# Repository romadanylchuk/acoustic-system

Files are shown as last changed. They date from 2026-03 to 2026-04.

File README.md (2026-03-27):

# Акустична розвідувальна система

Система акустичної розвідки для спостережного пункту (СП) у польових умовах.

## Структура проекту

```
acoustic-system/
├── docs/
│   ├── acoustic_system_context.md      # Контекст проекту (для Claude)
│   └── bom_acoustic_system_v2.xlsx     # Специфікація комплектуючих
├── hardware/
│   ├── station_battery_mount.scad      # Акумуляторний відсік + кріплення
│   ├── station_electronics_compartment.scad  # Електронний відсік
│   └── station_mic_lid.scad            # Мікрофонна кришка
├── firmware/
│   ├── station/                        # Прошивка ESP32-S3 (автономна станція)
│   └── gateway/                        # Прошивка TTGO LoRa32 (базова станція)
├── server/                             # Серверна частина (Rock Pi 4C+)
└── README.md
```

## Відновлення контексту в Claude Code

```bash
claude
```

Після запуску:
```
Прочитай docs/acoustic_system_context.md і продовжимо розробку
```

## Поточний статус

- [x] Архітектура системи
- [x] Специфікація комплектуючих
- [x] 3D моделі корпусу (SCAD)
- [ ] Етап 1: Прошивка ESP32-S3 — 4-канальний запис + GCC-PHAT TDOA
- [ ] Етап 2: Протокол LoRa + передача аудіо
- [ ] Етап 3: Тестування на вулиці
- [ ] Етап 4: Серверна обробка + інтерфейс

## Тестова конфігурація

```
2× Автономна станція  (ESP32-S3 + 4×INMP441 + LoRa + nRF24)
1× Базова станція     (Rock Pi 4C+ + TTGO LoRa32 комунікаційний модуль)
Розміщення: трикутник ~300м сторона
```

## Апаратне забезпечення

| Компонент | Модель | К-сть |
|---|---|---|
| МК станції | ESP32-S3-DevKitC-1 N16R8 | 3 |
| Мікрофони | INMP441 I2S | 20 |
| Акумулятори | Li-Ion 21700 (2S2P на станцію) | 8 |
| LoRa | Ra-02 SX1278 433МГц | 2 |
| 2.4ГГц | nRF24L01 PA+LNA | 3 |
| RTC | DS3231 | 2 |
| DC-DC | Mini360 | 2 |
| BMS станції | 2S Li-Ion 8.4В | 2 |
| Одноплатний ПК | Rock Pi 4C+ | 1 |
| Комунікаційний модуль | TTGO LoRa32 SX1278 | 1 |
| BMS база | 4S Li-Ion 16.8В | 1 |
| DC-DC база | XL4016 | 1 |

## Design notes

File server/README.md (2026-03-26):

# Серверна частина (Rock Pi 4C+)

TTGO LoRa32 підключається до Rock Pi по USB/UART як комунікаційний модуль.
USB мікрофон підключається напряму до Rock Pi (станція 0).

## TODO

- [ ] Прийом даних від TTGO по USB/UART
- [ ] Розшифрування AES-128-CCM LoRa пакетів (counter + MIC верифікація)
- [ ] Тріангуляція позиції джерела звуку (6 TDOA пар на станцію)
- [ ] Класифікація нейромережею
- [ ] Трекінг переміщення
- [ ] Інтерфейс оператора (карта)

## Алгоритми

### Тріангуляція

1. **Bearing Intersection** — перетин напрямних від станцій
2. **TDOA між станціями** — по різниці часу надходження події

### Класифікація

Нейромережева класифікація джерела:
- Людина (кроки, голос)
- Тварина
- Транспорт (колісний, гусеничний)
- Невідомо

## Залежності (Python)

```
numpy
scipy
torch або tflite
pyserial
folium або leaflet (карта)
```

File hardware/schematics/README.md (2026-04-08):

# hardware/schematics — Текстові нетлісти схем

Цей каталог містить текстові нетлісти у форматі, сумісному з KiCad 8, для майбутнього проектування друкованих плат акустичної розвідувальної системи.

## Файли

| Файл | Опис |
|---|---|
| `station_netlist.txt` | Нетліст автономної станції (ESP32-S3 N16R8): 4× INMP441 по двох шинах I2S, Ra-02 SX1278 LoRa (SPI), nRF24L01 PA+LNA (спільна SPI шина з LoRa), DS3231 RTC (I2C), рейки живлення від LiFePO4 |
| `gateway_netlist.txt` | Нетліст шлюзу (TTGO LoRa32): зовнішній nRF24L01 PA+LNA (SPI), вбудований SX1278 LoRa 433 MHz, вбудований OLED-дисплей SSD1306, UART до сервера Rock Pi 4C+ |

## Формат та інструменти

Файли написані в S-expression форматі `(net-list ...)` — текстовий опис з'єднань.

**Інструмент:** KiCad 8 — редактор схем і трасування ДП.

## Воркфлоу редагування схем

**Джерело правди — `.kicad_sch` файли (KiCad S-expression).**

1. Перший `.kicad_sch` генерується з нетлісту (одноразово).
2. Розкладка компонентів робиться вручну в KiCad Eeschema (одноразово).
3. Всі подальші правки вносяться **напряму в `.kicad_sch`** — Claude може редагувати цей формат як текст.
4. Перегляд — відкрити/перезавантажити файл в KiCad Eeschema.

**Чому не skidl:** skidl при перегенерації скидає ручне розкладання компонентів. Для схем зі стабільною топологією це зайвий overhead.

```
Описати помилку → Claude править .kicad_sch → перевідкрити в KiCad → layout збережено
```

## Параметри запису (прототип)

- Частота дискретизації: **32 000 Гц / 16-bit**, 4 канали
- Кільцевий буфер: 32000 × 4 кан. × 2 байт × 15 с = **3.84 МБ** (в межах 8 МБ PSRAM модуля N16R8)
- Смуга: 16 кГц — покриває акустичні сигнатури БПЛА

## Серійний зразок (цільова апаратна платформа)

Серійна версія передбачає перехід на підвищені характеристики:

| Параметр | Прототип | Серійний зразок |
|---|---|---|
| МК | ESP32-S3 N16R8 | **STM32H743** |
| Мікрофони | INMP441 | **ICS-43434** (±0.5° фазова узгодженість) |
| Частота дискретизації | 32 000 Гц / 16-bit | **44 100 Гц / 24-bit** |
| Смуга | 16 кГц | 20 кГц |
| Буфер | 3.84 МБ | ~7.9 МБ (потребує зовнішнього SDRAM або ≤10 с буфера) |

Нетлісти для серійної версії будуть додані окремо після уточнення схемотехніки STM32H743.

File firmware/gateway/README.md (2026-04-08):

# Прошивка комунікаційного модуля (TTGO LoRa32)

TTGO LoRa32 — радіоміст між автономними станціями та Rock Pi 4C+.
Мікрофон СП (USB) підключається напряму до Rock Pi.

## TODO

- [ ] Прийом LoRa метаданих від автономних станцій
- [ ] Передача даних на Rock Pi по USB/UART
- [ ] Прийом аудіофрагментів по nRF24L01
- [ ] Відображення статусу на OLED дисплеї

## Підключення

### nRF24L01 (SPI)

| nRF24 | TTGO ESP32 | Примітка |
|---|---|---|
| MOSI | GPIO 13 | HSPI |
| MISO | GPIO 12 | HSPI |
| SCK | GPIO 15 | HSPI |
| CSN | GPIO 2 | |
| CE | GPIO 17 | |
| IRQ | GPIO 16 | |

> nRF24 підключений на HSPI шину — не конфліктує з вбудованим LoRa SX1278 (VSPI: MOSI=27, MISO=19, SCK=5, NSS=18). Firmware ініціалізує дві окремі SPI шини.

### OLED дисплей (вбудований на TTGO)

| Функція | Відображення |
|---|---|
| Рядок 1 | Кількість активних станцій |
| Рядок 2 | Остання подія (клас + час) |
| Рядок 3 | Рівень сигналу LoRa |
| Рядок 4 | Статус синхронізації |

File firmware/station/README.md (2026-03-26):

# Прошивка автономної станції (ESP32-S3)

## Конфігурація I2S (прототип)

| Параметр | Значення | Примітка |
|---|---|---|
| Sample rate | **32 000 Гц** | Bandwidth 16 kHz — покриває сигнатури БПЛА |
| Bit depth | **16 bit** | Зменшує вдвічі розмір буфера відносно 32-bit |
| Канали | 4 (2× I2S bus) | M1–M4 на шинах 0 і 1 |
| Ring buffer | 32000 × 4 × 2 × 15 с = **3.84 МБ** | Вміщується в 8 МБ PSRAM |

> **Серійний зразок (STM32H743 + ICS-43434):** підвищити до 44 100 Гц / 24-bit.
> ICS-43434 покриває до 20 kHz (±0.5° фазова узгодженість), що дає повний спектр
> для класифікації БПЛА і покращує роздільну здатність GCC-PHAT TDOA приблизно вдвічі.
> Buffer при цьому: 44100 × 4 × 3 × 15 с ≈ 7.9 МБ — потребує зовнішнього SDRAM або
> скорочення буфера до 10 с.

## Етап 1 — TODO

- [ ] Синхронний запис 4 каналів I2S (4× INMP441)
- [ ] Кільцевий буфер 10-15 сек в PSRAM (~3.84 МБ при 32кГц × 16bit × 4ch × 15s)
- [ ] GCC-PHAT алгоритм для TDOA між мікрофонами (6 пар)
- [ ] Попередня класифікація події
- [ ] Watchdog timer (обов'язково для автономної польової роботи)
- [ ] Deep sleep / light sleep керування живленням (~56мВт у режимі очікування)
- [ ] Пробудження через аналоговий компаратор (звуковий тригер)
- [ ] Читання температури з DS3231 (корекція швидкості звуку)
- [ ] Стратегія розподілу PSRAM (ring buffer + робочі буфери GCC-PHAT)
- [ ] SPI mutex для спільної шини LoRa + nRF24 (пріоритет: LoRa > nRF24)

## Етап 2 — TODO

- [ ] LoRa передача метаданих (Ra-02 SX1278)
- [ ] AES-128-CCM шифрування + автентифікація LoRa пакетів (pre-shared key)
- [ ] Прийом запиту з базової станції
- [ ] Передача аудіофрагменту по nRF24L01
- [ ] Переривання nRF24 передачі для пріоритетного LoRa пакету (SPI arbitration)

## Підключення

### INMP441 мікрофони (I2S)

| INMP441 | ESP32-S3 | Примітка |
|---|---|---|
| VDD | 3.3В | |
| GND | GND | |
| SCK | GPIO 14 | I2S шина 0 |
| WS | GPIO 15 | I2S шина 0 |
| SD | GPIO 16 | M1 (L/R=GND) |
| SD | GPIO 17 | M2 (L/R=3.3В) |
| SCK | GPIO 18 | I2S шина 1 |
| WS | GPIO 19 | I2S шина 1 |
| SD | GPIO 20 | M3 (L/R=GND) |
| SD | GPIO 21 | M4 (L/R=3.3В) |

### Ra-02 LoRa (SPI)

| Ra-02 | ESP32-S3 |
|---|---|
| MOSI | GPIO 11 |
| MISO | GPIO 13 |
| SCK | GPIO 12 |
| NSS | GPIO 10 |
| DIO0 | GPIO 9 |
| RST | GPIO 8 |

### nRF24L01 (SPI — спільна шина з LoRa)

| nRF24 | ESP32-S3 |
|---|---|
| MOSI | GPIO 11 |
| MISO | GPIO 13 |
| SCK | GPIO 12 |
| CSN | GPIO 7 |
| CE | GPIO 6 |
| IRQ | GPIO 5 |

### DS3231 RTC (I2C)

| DS3231 | ESP32-S3 |
|---|---|
| SDA | GPIO 3 |
| SCL | GPIO 4 |
| VCC | 3.3В |
| GND | GND |

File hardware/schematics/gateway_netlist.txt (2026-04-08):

;; KiCad-compatible Text Netlist
;; Gateway Node — TTGO LoRa32 (ESP32 + onboard SX1278 LoRa)
;; Acoustic Reconnaissance System — Gateway / Command Post (CP) Node
;; Generated from: firmware/gateway/README.md + docs/acoustic_system_context.md

(net-list
  (version 1)
  (design
    (source "acoustic-system/hardware/schematics/gateway_netlist.txt")
    (date "2026-03-23")
    (tool "hand-written / KiCad 8 compatible")
    (comment_1 "Board: TTGO LoRa32 (LILYGO T3 v1.6 or similar)")
    (comment_2 "MCU: ESP32 dual-core 240MHz, 4MB Flash, 8MB PSRAM (variant dependent)")
    (comment_3 "Onboard LoRa: SX1278 433MHz — connected internally, not in this netlist")
    (comment_4 "Onboard OLED: SSD1306 0.96\" 128x64 — connected internally via I2C")
    (comment_5 "External nRF24L01 PA+LNA connected via standard SPI pins")
  )

  ;; =========================================================
  ;; COMPONENTS
  ;; =========================================================

  (components

    ;; --- MCU + onboard peripherals ---
    (comp (ref U1)
      (value "TTGO LoRa32 ESP32")
      (description "ESP32 module on TTGO LoRa32 board. Onboard: SX1278 LoRa 433MHz, SSD1306 OLED 0.96\", LiPo charger")
    )

    ;; --- Onboard LoRa (internal wiring, informational) ---
    (comp (ref U2)
      (value "SX1278 (onboard)")
      (description "Onboard LoRa 433MHz transceiver on TTGO LoRa32. Internally wired to ESP32 SPI bus. Receives metadata packets from autonomous stations via FHSS.")
    )

    ;; --- Onboard OLED (internal wiring, informational) ---
    (comp (ref DSP1)
      (value "SSD1306 OLED 0.96\" (onboard)")
      (description "Onboard 128x64 OLED display on TTGO LoRa32. Internally wired via I2C. Shows: active station count, last event class+time, LoRa RSSI, sync status.")
    )

    ;; --- External nRF24L01 ---
    (comp (ref U3)
      (value "nRF24L01 PA+LNA")
      (description "External 2.4GHz radio module for on-demand audio fragment retrieval from autonomous stations. PA+LNA variant for extended range.")
    )

    ;; --- Power ---
    (comp (ref REG1)
      (value "3.3V onboard LDO")
      (description "3.3V regulator on TTGO LoRa32 board")
    )
  )

  ;; =========================================================
  ;; NETS
  ;; =========================================================

  (nets

    ;; ---------------------------------------------------------
    ;; POWER RAILS
    ;; ---------------------------------------------------------

    (net (name "+3V3")
      (node (ref U1)   (pin VDD))
      (node (ref U2)   (pin VCC))      ;; onboard, internal connection
      (node (ref DSP1) (pin VCC))      ;; onboard, internal connection
      (node (ref U3)   (pin VCC))
      (node (ref REG1) (pin OUT))
    )

    (net (name "GND")
      (node (ref U1)   (pin GND))
      (node (ref U2)   (pin GND))      ;; onboard, internal connection
      (node (ref DSP1) (pin GND))      ;; onboard, internal connection
      (node (ref U3)   (pin GND))
      (node (ref REG1) (pin GND))
    )

    ;; ---------------------------------------------------------
    ;; SPI BUS — external nRF24L01 PA+LNA
    ;; Uses HSPI bus (GPIO13/12/15) — free from LoRa conflicts.
    ;; TTGO T3 v1.6 LoRa uses: MOSI=27, MISO=19, SCK=5, NSS=18, RST=23
    ;; nRF24 is placed on separate HSPI to avoid conflicts.
    ;; ---------------------------------------------------------

    (net (name "NRF_SPI_MOSI")
      (node (ref U1)  (pin GPIO13))
      (node (ref U3)  (pin MOSI))
    )

    (net (name "NRF_SPI_MISO")
      (node (ref U1)  (pin GPIO12))
      (node (ref U3)  (pin MISO))
    )

    (net (name "NRF_SPI_SCK")
      (node (ref U1)  (pin GPIO15))
      (node (ref U3)  (pin SCK))
    )

    ;; ---------------------------------------------------------
    ;; nRF24L01 PA+LNA — control signals
    ;; ---------------------------------------------------------

    (net (name "NRF_CSN")
      (node (ref U1)  (pin GPIO2))
      (node (ref U3)  (pin CSN))
    )

    (net (name "NRF_CE")
      (node (ref U1)  (pin GPIO17))
      (node (ref U3)  (pin CE))
      ;; CE: chip enable — activates RX/TX mode
    )

    (net (name "NRF_IRQ")
      (node (ref U1)  (pin GPIO16))
      (node (ref U3)  (pin IRQ))
      ;; IRQ: active-low interrupt from nRF24 to MCU
    )

    ;; ---------------------------------------------------------
    ;; ONBOARD LoRa SX1278 — internal connections (informational)
    ;; Exact internal pin mapping varies by TTGO LoRa32 revision.
    ;; Common wiring for TTGO T3 v1.6:
    ;;   MOSI=GPIO27, MISO=GPIO19, SCK=GPIO5, NSS=GPIO18,
    ;;   DIO0=GPIO26, RST=GPIO23
    ;; Check board schematic for exact revision.
    ;; ---------------------------------------------------------

    (net (name "LORA_SPI_MOSI_INTERNAL")
      (node (ref U1)  (pin GPIO27))    ;; TTGO T3 v1.6 typical
      (node (ref U2)  (pin MOSI))
    )

    (net (name "LORA_SPI_MISO_INTERNAL")
      (node (ref U1)  (pin GPIO19))    ;; shared MISO on some revisions
      (node (ref U2)  (pin MISO))
    )

    (net (name "LORA_SPI_SCK_INTERNAL")
      (node (ref U1)  (pin GPIO5))     ;; TTGO T3 v1.6 typical
      (node (ref U2)  (pin SCK))
    )

    (net (name "LORA_NSS_INTERNAL")
      (node (ref U1)  (pin GPIO18))    ;; TTGO T3 v1.6 typical
      (node (ref U2)  (pin NSS))
    )

    (net (name "LORA_DIO0_INTERNAL")
      (node (ref U1)  (pin GPIO26))    ;; TTGO T3 v1.6 typical
      (node (ref U2)  (pin DIO0))
    )

    (net (name "LORA_RST_INTERNAL")
      (node (ref U1)  (pin GPIO23))    ;; TTGO T3 v1.6 typical
      (node (ref U2)  (pin RST))
    )

    ;; ---------------------------------------------------------
    ;; ONBOARD OLED SSD1306 — internal I2C connections (informational)
    ;; Common on TTGO LoRa32: SDA=GPIO21, SCL=GPIO22
    ;; ---------------------------------------------------------

    (net (name "I2C_SDA_INTERNAL")
      (node (ref U1)   (pin GPIO21))
      (node (ref DSP1) (pin SDA))
    )

    (net (name "I2C_SCL_INTERNAL")
      (node (ref U1)   (pin GPIO22))
      (node (ref DSP1) (pin SCL))
    )

    ;; ---------------------------------------------------------
    ;; USB/UART TO HOST (Rock Pi 4C+ server)
    ;; TTGO onboard USB-to-UART via CP2102 or CH340
    ;; Gateway relays LoRa metadata to server over serial
    ;; ---------------------------------------------------------

    (net (name "UART_TX_TO_HOST")
      (node (ref U1)  (pin TXD0))
      ;; Connected through onboard USB-UART chip to Rock Pi USB port
    )

    (net (name "UART_RX_FROM_HOST")
      (node (ref U1)  (pin RXD0))
      ;; Control commands from Rock Pi to gateway
    )

  ) ;; end nets

) ;; end net-list

;; =========================================================
;; PIN ASSIGNMENT SUMMARY — TTGO LoRa32 ESP32
;; =========================================================
;;
;;  GPIO  | Net Name                  | Connected To
;; -------|---------------------------|----------------------------
;;   2    | NRF_CSN                   | nRF24L01 CSN
;;   5    | LORA_SPI_SCK_INTERNAL     | SX1278 SCK  (onboard)
;;  12    | NRF_SPI_MISO              | nRF24L01 MISO  (HSPI)
;;  13    | NRF_SPI_MOSI              | nRF24L01 MOSI  (HSPI)
;;  15    | NRF_SPI_SCK               | nRF24L01 SCK   (HSPI)
;;  16    | NRF_IRQ                   | nRF24L01 IRQ
;;  17    | NRF_CE                    | nRF24L01 CE
;;  18    | LORA_NSS_INTERNAL         | SX1278 NSS  (onboard)
;;  19    | LORA_SPI_MISO_INTERNAL    | SX1278 MISO (onboard)
;;  21    | I2C_SDA_INTERNAL          | SSD1306 SDA (onboard)
;;  22    | I2C_SCL_INTERNAL          | SSD1306 SCL (onboard)
;;  23    | LORA_RST_INTERNAL         | SX1278 RST  (onboard)
;;  26    | LORA_DIO0_INTERNAL        | SX1278 DIO0 (onboard)
;;  27    | LORA_SPI_MOSI_INTERNAL    | SX1278 MOSI (onboard)
;;
;; nRF24 placed on HSPI (GPIO12/13/15) — no conflicts with onboard LoRa SPI.
;; Firmware must initialise two SPI buses: VSPI for LoRa (internal), HSPI for nRF24.
;;
;; =========================================================
;; OLED STATUS DISPLAY (onboard SSD1306)
;; =========================================================
;;
;;  Line 1: Number of active autonomous stations
;;  Line 2: Last event — class + timestamp
;;  Line 3: LoRa RSSI / signal level
;;  Line 4: Time synchronisation status
;;
;; =========================================================
;; GATEWAY ROLE IN SYSTEM
;; =========================================================
;;
;;  - Receives LoRa 433MHz FHSS metadata packets from all stations
;;  - Forwards decoded metadata to Rock Pi 4C+ server via USB/UART
;;  - Receives audio-request commands from server
;;  - Transmits nRF24L01 audio-pull requests to target station
;;  - Receives compressed Opus audio (16kHz mono, 32kbps) via nRF24
;;  - Relays audio stream to server for classification and archiving
;;
;; =========================================================

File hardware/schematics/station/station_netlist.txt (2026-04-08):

;; KiCad-compatible Text Netlist
;; Autonomous Station — ESP32-S3 (N16R8: 8MB Flash + 8MB PSRAM)
;; Acoustic Reconnaissance System — Station Node
;; I2S recording: 32 000 Hz / 16-bit, 4 channels, ring buffer 3.84 MB in PSRAM
;; Generated from: firmware/station/README.md + docs/acoustic_system_context.md
;; Serial version target: STM32H743 + ICS-43434 @ 44 100 Hz / 24-bit

(net-list
  (version 1)
  (design
    (source "acoustic-system/hardware/schematics/station_netlist.txt")
    (date "2026-03-23")
    (tool "hand-written / KiCad 8 compatible")
    (comment_1 "Prototype MCU: ESP32-S3-DevKitC-1 N16R8")
    (comment_2 "Serial MCU target: STM32H743")
    (comment_3 "I2S sample rate: 32 000 Hz / 16-bit (prototype)")
    (comment_4 "Serial version: 44 100 Hz / 24-bit with ICS-43434 microphones")
  )

  ;; =========================================================
  ;; COMPONENTS
  ;; =========================================================

  (components

    ;; --- MCU ---
    (comp (ref U1)
      (value "ESP32-S3-DevKitC-1 N16R8")
      (description "Dual-core 240MHz, 8MB Flash, 8MB PSRAM")
    )

    ;; --- Microphones (I2S Bus 0) ---
    (comp (ref MIC1)
      (value "INMP441")
      (description "I2S MEMS microphone, M1, L/R pin = GND (left channel)")
    )
    (comp (ref MIC2)
      (value "INMP441")
      (description "I2S MEMS microphone, M2, L/R pin = VCC (right channel)")
    )

    ;; --- Microphones (I2S Bus 1) ---
    (comp (ref MIC3)
      (value "INMP441")
      (description "I2S MEMS microphone, M3, L/R pin = GND (left channel)")
    )
    (comp (ref MIC4)
      (value "INMP441")
      (description "I2S MEMS microphone, M4, L/R pin = VCC (right channel)")
    )

    ;; --- LoRa Radio ---
    (comp (ref U2)
      (value "Ra-02 SX1278")
      (description "LoRa module 433 MHz, FHSS, SPI interface")
    )

    ;; --- 2.4 GHz Radio ---
    (comp (ref U3)
      (value "nRF24L01 PA+LNA")
      (description "2.4 GHz radio, SPI shared with LoRa, on-demand audio transfer")
    )

    ;; --- RTC ---
    (comp (ref U4)
      (value "DS3231")
      (description "RTC with TCXO, I2C interface, temperature sensor for sound-speed correction")
    )

    ;; --- Power ---
    (comp (ref REG1)
      (value "Mini360 DC-DC buck")
      (description "DC-DC buck converter 7.4V->3.3V, ~90% efficiency")
    )
    (comp (ref BAT1)
      (value "Li-Ion 21700 x4 (2S2P)")
      (description "4x Li-Ion 21700 cells: 2S2P, 7.4V nominal / 8.4V charged / 6.0V cutoff, ~9Ah, ~67Wh. BMS 2S required.")
    )
  )

  ;; =========================================================
  ;; NETS
  ;; =========================================================

  (nets

    ;; ---------------------------------------------------------
    ;; POWER RAILS
    ;; ---------------------------------------------------------

    (net (name "+3V3")
      (node (ref U1)   (pin VDD))
      (node (ref MIC1) (pin VDD))
      (node (ref MIC2) (pin VDD))
      (node (ref MIC2) (pin LR))       ;; MIC2 L/R=VCC -> right channel
      (node (ref MIC3) (pin VDD))
      (node (ref MIC4) (pin VDD))
      (node (ref MIC4) (pin LR))       ;; MIC4 L/R=VCC -> right channel
      (node (ref U2)   (pin VCC))
      (node (ref U3)   (pin VCC))
      (node (ref U4)   (pin VCC))
      (node (ref REG1) (pin OUT))
    )

    (net (name "GND")
      (node (ref U1)   (pin GND))
      (node (ref MIC1) (pin GND))
      (node (ref MIC1) (pin LR))       ;; MIC1 L/R=GND -> left channel
      (node (ref MIC2) (pin GND))
      (node (ref MIC3) (pin GND))
      (node (ref MIC3) (pin LR))       ;; MIC3 L/R=GND -> left channel
      (node (ref MIC4) (pin GND))
      (node (ref U2)   (pin GND))
      (node (ref U3)   (pin GND))
      (node (ref U4)   (pin GND))
      (node (ref REG1) (pin GND))
      (node (ref BAT1) (pin NEG))
    )

    (net (name "VBAT")
      (node (ref BAT1) (pin POS))
      (node (ref REG1) (pin IN))
    )

    ;; ---------------------------------------------------------
    ;; I2S BUS 0 — MIC1 (M1) and MIC2 (M2)
    ;; ESP32-S3: SCK=GPIO14, WS=GPIO15
    ;; ---------------------------------------------------------

    (net (name "I2S0_SCK")
      (node (ref U1)   (pin GPIO14))
      (node (ref MIC1) (pin SCK))
      (node (ref MIC2) (pin SCK))
    )

    (net (name "I2S0_WS")
      (node (ref U1)   (pin GPIO15))
      (node (ref MIC1) (pin WS))
      (node (ref MIC2) (pin WS))
    )

    (net (name "I2S0_DATA_M1")
      (node (ref U1)   (pin GPIO16))
      (node (ref MIC1) (pin SD))
      ;; MIC1: L/R=GND => left channel, drives SD when WS=low
    )

    (net (name "I2S0_DATA_M2")
      (node (ref U1)   (pin GPIO17))
      (node (ref MIC2) (pin SD))
      ;; MIC2: L/R=VCC => right channel, drives SD when WS=high
    )

    ;; ---------------------------------------------------------
    ;; I2S BUS 1 — MIC3 (M3) and MIC4 (M4)
    ;; ESP32-S3: SCK=GPIO18, WS=GPIO19
    ;; ---------------------------------------------------------

    (net (name "I2S1_SCK")
      (node (ref U1)   (pin GPIO18))
      (node (ref MIC3) (pin SCK))
      (node (ref MIC4) (pin SCK))
    )

    (net (name "I2S1_WS")
      (node (ref U1)   (pin GPIO19))
      (node (ref MIC3) (pin WS))
      (node (ref MIC4) (pin WS))
    )

    (net (name "I2S1_DATA_M3")
      (node (ref U1)   (pin GPIO20))
      (node (ref MIC3) (pin SD))
      ;; MIC3: L/R=GND => left channel
    )

    (net (name "I2S1_DATA_M4")
      (node (ref U1)   (pin GPIO21))
      (node (ref MIC4) (pin SD))
      ;; MIC4: L/R=VCC => right channel
    )

    ;; ---------------------------------------------------------
    ;; SPI BUS (shared) — Ra-02 LoRa + nRF24L01
    ;; ESP32-S3: MOSI=GPIO11, MISO=GPIO13, SCK=GPIO12
    ;; Chip selects are separate (LORA_NSS, NRF_CSN)
    ;; ---------------------------------------------------------

    (net (name "SPI_MOSI")
      (node (ref U1)  (pin GPIO11))
      (node (ref U2)  (pin MOSI))
      (node (ref U3)  (pin MOSI))
    )

    (net (name "SPI_MISO")
      (node (ref U1)  (pin GPIO13))
      (node (ref U2)  (pin MISO))
      (node (ref U3)  (pin MISO))
    )

    (net (name "SPI_SCK")
      (node (ref U1)  (pin GPIO12))
      (node (ref U2)  (pin SCK))
      (node (ref U3)  (pin SCK))
    )

    ;; ---------------------------------------------------------
    ;; LoRa Ra-02 SX1278 — control signals
    ;; ---------------------------------------------------------

    (net (name "LORA_NSS")
      (node (ref U1)  (pin GPIO10))
      (node (ref U2)  (pin NSS))
    )

    (net (name "LORA_DIO0")
      (node (ref U1)  (pin GPIO9))
      (node (ref U2)  (pin DIO0))
      ;; DIO0: interrupt line — RxDone / TxDone / CadDone
    )

    (net (name "LORA_RST")
      (node (ref U1)  (pin GPIO8))
      (node (ref U2)  (pin RST))
    )

    ;; ---------------------------------------------------------
    ;; nRF24L01 PA+LNA — control signals
    ;; ---------------------------------------------------------

    (net (name "NRF_CSN")
      (node (ref U1)  (pin GPIO7))
      (node (ref U3)  (pin CSN))
    )

    (net (name "NRF_CE")
      (node (ref U1)  (pin GPIO6))
      (node (ref U3)  (pin CE))
      ;; CE: chip enable — activates RX/TX mode
    )

    (net (name "NRF_IRQ")
      (node (ref U1)  (pin GPIO5))
      (node (ref U3)  (pin IRQ))
      ;; IRQ: active-low interrupt from nRF24 to MCU
    )

    ;; ---------------------------------------------------------
    ;; I2C BUS — DS3231 RTC
    ;; ESP32-S3: SDA=GPIO3, SCL=GPIO4
    ;; ---------------------------------------------------------

    (net (name "I2C_SDA")
      (node (ref U1)  (pin GPIO3))
      (node (ref U4)  (pin SDA))
    )

    (net (name "I2C_SCL")
      (node (ref U1)  (pin GPIO4))
      (node (ref U4)  (pin SCL))
    )

  ) ;; end nets

) ;; end net-list

;; =========================================================
;; PIN ASSIGNMENT SUMMARY — ESP32-S3
;; =========================================================
;;
;;  GPIO  | Net Name         | Connected To
;; -------|------------------|-------------------------------
;;    3   | I2C_SDA          | DS3231 SDA
;;    4   | I2C_SCL          | DS3231 SCL
;;    5   | NRF_IRQ          | nRF24L01 IRQ
;;    6   | NRF_CE           | nRF24L01 CE
;;    7   | NRF_CSN          | nRF24L01 CSN
;;    8   | LORA_RST         | Ra-02 RST
;;    9   | LORA_DIO0        | Ra-02 DIO0
;;   10   | LORA_NSS         | Ra-02 NSS
;;   11   | SPI_MOSI         | Ra-02 MOSI + nRF24L01 MOSI
;;   12   | SPI_SCK          | Ra-02 SCK  + nRF24L01 SCK
;;   13   | SPI_MISO         | Ra-02 MISO + nRF24L01 MISO
;;   14   | I2S0_SCK         | MIC1 SCK, MIC2 SCK
;;   15   | I2S0_WS          | MIC1 WS,  MIC2 WS
;;   16   | I2S0_DATA_M1     | MIC1 SD   (L/R=GND, left)
;;   17   | I2S0_DATA_M2     | MIC2 SD   (L/R=VCC, right)
;;   18   | I2S1_SCK         | MIC3 SCK, MIC4 SCK
;;   19   | I2S1_WS          | MIC3 WS,  MIC4 WS
;;   20   | I2S1_DATA_M3     | MIC3 SD   (L/R=GND, left)
;;   21   | I2S1_DATA_M4     | MIC4 SD   (L/R=VCC, right)
;;
;; =========================================================
;; MICROPHONE TETRAHEDRAL ARRAY GEOMETRY
;; =========================================================
;;
;;  MIC1 (M1) — top apex of tetrahedron (vertical, pointing up)
;;  MIC2 (M2) — 35° tilt from vertical, azimuth 0°
;;  MIC3 (M3) — 35° tilt from vertical, azimuth 120°
;;  MIC4 (M4) — 35° tilt from vertical, azimuth 240°
;;
;;  35.26° tilt = true regular tetrahedron geometry
;;  Enables 3D direction-of-arrival: azimuth + elevation
;;  GCC-PHAT TDOA computed between all mic pairs.
;;  Temperature from DS3231 used for sound-speed correction
;;  (approx. 0.6 m/s per degree Celsius).
;;
;; =========================================================
;; RECORDING PARAMETERS
;; =========================================================
;;
;;  Prototype:    32 000 Hz / 16-bit / 4 channels
;;                Ring buffer: 32000 x 4ch x 2B x 15s = 3.84 MB
;;                Fits in 8 MB PSRAM (N16R8 module)
;;                Bandwidth: 16 kHz (covers UAV acoustic signatures)
;;
;;  Serial version target (future):
;;                44 100 Hz / 24-bit / 4 channels
;;                MCU: STM32H743, Mics: ICS-43434
;;                Buffer: ~7.9 MB — requires external SDRAM or <=10s buffer
;;
;; =========================================================

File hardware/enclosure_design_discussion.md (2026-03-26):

# Обговорення концепції нового корпусу станції

> Статус: обговорення, до проектування не переходили.
> Дата: 2026-03-25

## Зміна підходу відносно попередньої версії

Попередня версія: верхня + нижня кришка, електроніка знизу.

**Нова концепція — навпаки:**
- Верхня частина = основний корпус (відкрита знизу "чашка"), містить всю електроніку.
- Нижня частина = плоска кришка, яка закриває корпус знизу.

---

## Верхній корпус (основна деталь)

- Відкритий знизу.
- **Верхня панель:** 4 отвори під мікрофони INMP441 у тетраедральній геометрії (1 центральний або зміщений + 3 по колу на 120°). Мікрофонні плати монтуються зсередини, притискаються до верхньої панелі.
- **Бічні стінки:** 2 роз'єми SMA — для LoRa 433MHz антени та nRF24 2.4GHz антени.
- **По внутрішньому периметру нижнього краю:** горизонтальний порожок (полиця/уступ) — кришка спирається по всьому колу (для ущільнювача і щільного прилягання).
- **У кутах:** циліндричні бонки з отворами під шурупи з потаєм.

## Нижня кришка

- Плоска пластина, "втоплена" в порожок — не виступає за межі стінок корпусу.
- По кутах: наскрізні отвори з потаєм під головку шурупа.
- Знизу: кріплення під батарейний відсік (обговорення окремо).

---

## Внутрішнє компонування (знизу вгору при збірці)

1. **Спочатку** — мікрофонні плати. Вставляються і фіксуються до верхньої панелі зсередини.
2. **Потім** — макетна/монтажна плата з основною електронікою: ESP32-S3, Ra-02 LoRa, nRF24L01, DS3231, перехідні роз'єми, з'єднувачі до мікрофонів і антенних роз'ємів.

---

## Основні параметри (вирішено)

| Параметр | Значення |
|---|---|
| Макетна плата | 70×90 мм, горизонтально |
| Кріплення плати | Пластикові бонки під саморізи (висота регульована) |
| Мікрофони | 4× INMP441, тетраедр, на верхній панелі |
| Антени | 2× SMA збоку |
| Батареї | 4× Li-ion 21700 (⌀21×70мм), схема 2S2P, знизу окремим відсіком |

## Відкриті питання

1. Відстань між мікрофонними платами і макетною платою (висота бонок).
2. Кріплення батарейного відсіку до нижньої кришки (знімний чи глухий, де роз'єм зарядки).
3. IP-клас захисту → геометрія ущільнювача в порожку.

---

## Інструментарій

- **3D моделювання:** build123d (Python)
- **Перегляд:** ocp-vscode (`show(obj)`)
- Старі .scad файли — legacy, не використовувати.

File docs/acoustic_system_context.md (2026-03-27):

# Акустична розвідувальна система — Контекст проекту

> Документ для відновлення контексту розробки. Вставити на початку нової сесії з Claude.

---

## 1. Концепція системи

**Призначення:** Акустична розвідка для спостережного пункту (СП) у польових умовах. Визначення джерела, напрямку і характеру звуку в реальному часі.

**Принцип роботи:** Мережа автономних акустичних станцій збирає звук, обчислює TDOA (різниця часу надходження між мікрофонами), передає метадані на СП. Сервер тріангулює точну позицію джерела звуку і класифікує його (людина / тварина / транспорт).

**Радіус покриття:** До 3-5 км від сервера. Відстань між станціями — до 500м.

**Час реакції:** Одиниці секунд — прийнятно.

---

## 2. Архітектура

**Топологія мережі:** Mesh — кожна станція є і сенсором, і ретранслятором. Немає єдиної точки відмови. При виході станції з ладу мережа перебудовується автоматично.

**Два радіоканали:**
- LoRa 433МГц (FHSS) — метадані подій, керуючі команди, синхронізація. Завжди активний, мінімальна радіопомітність. Шифрування AES-128-CCM (pre-shared key).
- 2.4ГГц nRF24L01 PA+LNA — аудіофрагменти. Вмикається тільки за запитом СП на 15-20 сек.

**Безпека радіоканалу:**
- AES-128-CCM шифрування + автентифікація всіх LoRa пакетів (вбудоване в ESP32)
- 4-байт лічильник пакетів (захист від replay-атак)
- 4-байт MIC (Message Integrity Code) — захист від підробки
- Pre-shared 128-біт ключ, унікальний для кожного розгортання

**Спільна SPI шина (LoRa + nRF24):**
- LoRa і nRF24 використовують одну SPI шину з окремими CS лініями
- Firmware mutex: одночасний доступ заборонений
- Пріоритет: LoRa пакет перериває nRF24 аудіо передачу (pause/resume)

**Передача аудіо за запитом:** Станція має кільцевий буфер 10-15 сек у PSRAM (pre+post trigger, ~3.84 МБ при 32кГц × 16bit × 4ch × 15s) ( Bandwidth 16 kHz покриває акустичні сигнатури БПЛА (основні гармоніки до 12 кГц)). Сервер отримує метадані від всіх станцій → обирає 1-2 з найкращим SNR → надсилає запит → станція вмикає 2.4ГГц передавач і відправляє стиснений фрагмент (Opus, 16кГц mono, ~32кбіт/с).

**Мікрофон на СП:** СП має власний USB мікрофон як нульова станція. Якщо подія близько (~200-500м) — аудіо є без запиту до станцій.

**3D локалізація:** Тетраедральний масив 4 мікрофонів на кожній станції дає 3D напрямок (азимут + елевація). Розташування: 1 мікрофон вгору, 3 по колу під 120° з нахилом 35° від вертикалі (≈35.26° — правильний тетраедр). TDOA обчислюється для всіх 6 пар мікрофонів (C(4,2)). Сервер тріангулює позицію методами Bearing Intersection + TDOA між станціями.

---

## 3. Апаратна частина станції

**Процесор:**
- Прототип: ESP32-S3-DevKitC-1 N16R8 (16МБ Flash + 8МБ PSRAM, dual-core 240МГц)
- Фінальна версія: STM32H743 (краща енергетика, 4× незалежних I2S шини)

**Мікрофони:** 4× INMP441 I2S модуль (прототип) або ICS-43434 (фінал, фазова узгодженість ±0.5°). Розташування тетраедральне. Вітрозахисні поролонові насадки обов'язкові.

> **Серійний зразок — збільшення смуги:** перехід на 44 100 Гц / 24-bit з мікрофонами ICS-43434 (частотна характеристика до 20 кГц). Дає повний спектр для класифікації БПЛА та подвоює роздільну здатність GCC-PHAT TDOA. Потребує зовнішнього SDRAM або скорочення ring buffer до 10 с (буфер ~7.9 МБ).

**Синхронізація часу:**
- TCXO ±0.5ppm на кожній станції (дрейф ~1.5мкс/год)
- Калібрування: акустичний маяк при розгортанні + взаємна корекція між станціями по LoRa
- БЕЗ GPS — вразливий до РЕБ

**Живлення:**
- Li-ion 21700, схема 2S2P (4 елементи): 7.4В номінал / 8.4В заряд / 6.0В відсічка
- Ємність: ~9А·год (2P × ~4.5А·год), енергія ~67Вт·год
- DC-DC buck конвертер 7.4В→3.3В обов'язковий (ESP32-S3 та вся периферія 3.3В)
- BMS: 2S балансуючий із захистом (перезаряд, переразряд, КЗ)
- Середнє споживання ~75мВт → автономність ~30 діб (при 0°C і вище, ККД buck ~90%)
- При -20°C: ~15-18 діб (Li-ion втрачає ~30-40% ємності на морозі — слабше ніж LiFePO4). Підігрів при температурі нижче -10°C

**Режими роботи:**
- Очікування (95% часу): мікроконтролер у light sleep, аналоговий компаратор слухає (~56мВт)
- Обробка події (4%): пробудження, 4-канальний запис, GCC-PHAT TDOA (6 пар), класифікація (~330мВт)
- Передача LoRa (1%): пакет ~50 байт (з AES-128-CCM) кожні кілька секунд (~400мВт × 0.5 сек)

**Firmware вимоги (ESP32-S3):**
- Watchdog timer — обов'язково для автономної роботи без обслуговування
- Deep sleep / light sleep — реалізація енергетичних режимів
- Аналоговий компаратор — пробудження по звуковому порогу
- Температура з DS3231 — корекція швидкості звуку (±0.6 м/с на °C)
- PSRAM: кільцевий буфер ~3.84 МБ + робочі буфери GCC-PHAT + стек
- SPI mutex (LoRa + nRF24): пріоритет LoRa, pause/resume для nRF24 аудіо

**Корпус:** IP65 пластик мінімум. Кабельні вводи PG7/PG9 для герметизації. Передбачити місце для сонячної панелі (не реалізовано, але конструктивно закладено).

---

## 4. Базова станція / СП

**Обладнання:**
- Rock Pi 4C+ (4ГБ) — основний обчислювальний модуль
- TTGO LoRa32 SX1278 — комунікаційний модуль (тільки LoRa прийом + nRF24 аудіо), USB/UART → Rock Pi
- ESP32-S3 N16R8 — станція 0: 4× INMP441, та сама прошивка що й польові станції, USB CDC → Rock Pi
- SSD 256ГБ для логів і аудіоархіву

**Програмна обробка:**
- Тріангуляція позиції (Bearing Intersection + TDOA між станціями)
- Класифікація звуку нейромережею (людина / тварина / транспорт / невідомо)
- Трекінг переміщення — побудова траєкторії об'єкта
- Фільтрація хибних спрацювань (дощ, вітер, птахи)
- Інтерфейс оператора — карта з позиціями подій

**Живлення СП:** 12В від авто акумулятора або окремий Li-Ion блок 100Вт·год.

---

## 5. Синхронізація без GPS (захист від РЕБ)

**Проблема:** GPS/GNSS вразливий до спуфінгу і придушення в умовах РЕБ. Втрата GPS одразу ламає TDOA між станціями.

**Рішення — акустичний маяк:** При розгортанні пристрій з відомими координатами генерує короткий імпульс за внутрішнім годинником. Всі станції фіксують час надходження → сервер обчислює відносні затримки → калібрує годинники. GPS потрібен тільки одноразово при встановленні (один пристрій, потім вимикається).

**Рішення — взаємна корекція:** Станції обмінюються мітками часу по LoRa mesh і взаємно коригують дрейф (distributed clock sync). Точність ~1-5мс — достатньо для тріангуляції на дистанціях 300-500м.

**Деградація без синхронізації:** TCXO дрейфує ~1.5мкс/год. Без корекції через 1 годину похибка позиції ~0.5м, через 24 години ~12м. Система продовжує працювати в деградованому режимі.

**Координати станцій:** Вимірюються одним GPS пристроєм послідовно при розгортанні. Вводяться в сервер вручну або передаються одноразово. Після цього GPS вимикається.

---

## 6. Тестова конфігурація (поточний етап)

**Склад тестової системи:**
- 2× автономні станції (ESP32-S3 N16R8 + 4×INMP441 + Ra-02 LoRa + nRF24L01 + Li-Ion 21700 2S2P)
- 1× базова станція — Rock Pi 4C+ + TTGO LoRa32 (комунікаційний модуль) + ESP32-S3 N16R8 (станція 0)
- Розміщення рівностороннім трикутником ~300м сторона

**Що перевіряємо:**
- TDOA локалізація всередині станції (напрямок на джерело звуку)
- Передача метаданих по LoRa
- Тріангуляція між 2 станціями + СП (3 точки = мінімум для 2D позиції)
- Протокол запиту і передачі аудіофрагменту
- Синхронізація часу між вузлами
- Енергетика і автономність в реальних умовах

**Етапи розробки:**

| Етап | Зміст | Тривалість |
|---|---|---|
| 1 | Один вузол на столі — 4-канальний запис + GCC-PHAT TDOA | 1-2 тижні |
| 2 | Зв'язок з базою — LoRa метадані + nRF24 аудіо протокол | 1 тиждень |
| 3 | Два вузли на вулиці — тріангуляція реального джерела, точність | 1-2 тижні |
| 4 | Програмна обробка на СП — карта, класифікація, інтерфейс | TBD |

**Поточний статус:** Закупка компонентів. Далі — Етап 1.

---

## 7. Ключові прийняті рішення

| Рішення | Обґрунтування |
|---|---|
| Без GPS | Вразливий до РЕБ. Синхронізація — акустичний маяк + TCXO + взаємна корекція |
| Двоканальна радіоархітектура | LoRa для метаданих (завжди), 2.4ГГц тільки для аудіо за запитом |
| AES-128-CCM шифрування | Захист від перехоплення, підробки і replay-атак на LoRa каналі |
| SPI mutex + пріоритет LoRa | LoRa і nRF24 на одній шині; LoRa пакет перериває nRF24 аудіо |
| Аудіо тільки за запитом | Економія енергії, зниження радіопомітності |
| Pre-trigger буфер | Запис починається ДО події — найцінніша частина звуку зберігається |
| LoRa FHSS | Стрибки по частотах — мінімальна помітність, стійкість до перешкод |
| Температурна поправка | Швидкість звуку змінюється 0.6м/с на градус, при 1-2км це метри похибки |
| Li-Ion 21700 (2S2P) | ~67Вт·год, ~30 діб автономності (0°C+, ККД buck 90%), BMS 2S 8.4В |
| Тетраедр 35° | Кут нахилу бічних мікрофонів ≈35.26° (правильний тетраедр) — оптимальна 3D точність |
| ESP32-S3 N16R8 для прототипу | 16МБ Flash (OTA dual partition) + 8МБ PSRAM; STM32H743 — фінальна версія |

---

## 8. Структура LoRa пакету (~50 байт, AES-128-CCM)

**Відкрита частина (AAD — authenticated but not encrypted):**

| Поле | Розмір | Зміст |
|---|---|---|
| Station ID | 2 байти | Ідентифікатор станції |
| Counter | 4 байти | Лічильник пакетів (захист від replay) |

**Зашифрована частина (ciphertext):**

| Поле | Розмір | Зміст |
|---|---|---|
| Timestamp | 8 байт | Мікросекунди, синхронізовано по TCXO |
| TDOA між мікрофонами | 6×4 байти | Всі 6 пар C(4,2) — попарні затримки |
| SNR по каналах | 4×1 байт | Рівень сигнал/шум кожного мікрофона |
| Клас події | 1 байт | Людина / тварина / транспорт / невідомо |
| Confidence | 1 байт | Впевненість класифікації (0-100%) |
| Рівень заряду | 1 байт | Відсоток заряду акумулятора |
| Температура | 1 байт | Для корекції швидкості звуку |

**Автентифікація:**

| Поле | Розмір | Зміст |
|---|---|---|
| MIC | 4 байти | Message Integrity Code (AES-128-CCM tag) |

**Разом:** 2 + 4 + 8 + 24 + 4 + 1 + 1 + 1 + 1 + 4 = **50 байт**

---

*Версія: 1.0 | Проект: Акустична розвідувальна система*

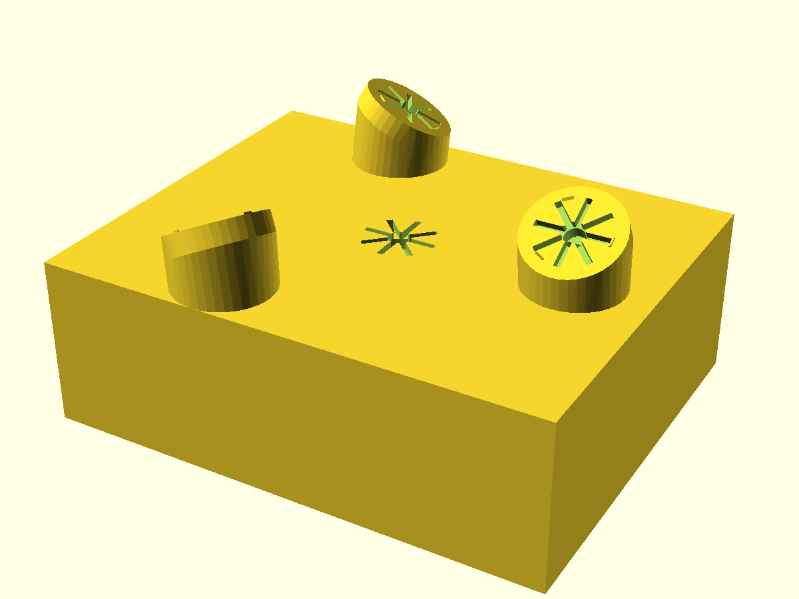
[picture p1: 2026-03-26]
hardware/station_mic_lid.png

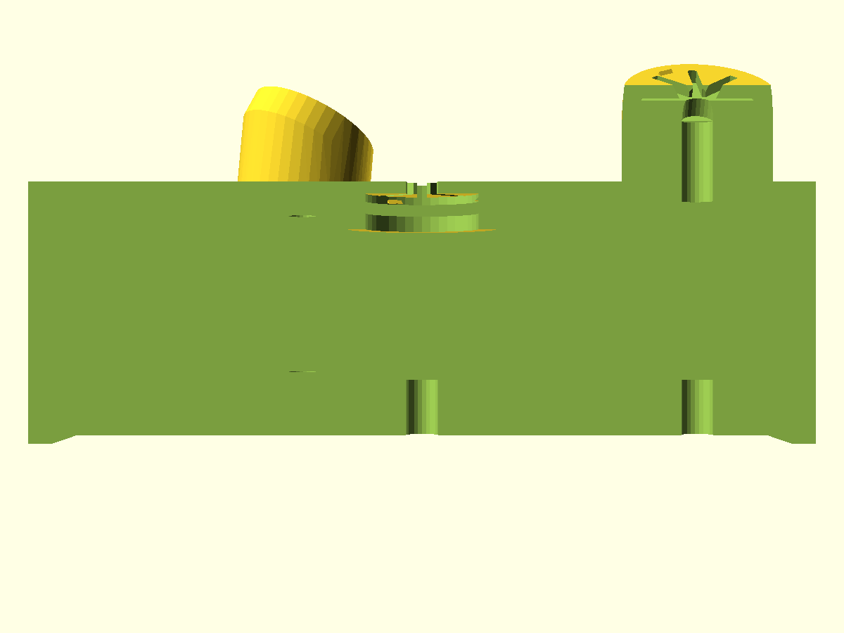
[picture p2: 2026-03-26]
hardware/mic_lid_section.png

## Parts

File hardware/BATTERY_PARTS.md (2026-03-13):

# Battery Compartment — File Structure

## Files

| File | Purpose |
|---|---|
| `station_battery_params.scad` | Shared parameters and computed dimensions — **edit here only** |
| `station_battery_mount.scad` | Body + stake mount — `include`s params |
| `station_battery_lid.scad` | Lid — `include`s params |

## Dependency

```
station_battery_params.scad
    ├── include → station_battery_mount.scad  (renders body + stake mount)
    └── include → station_battery_lid.scad    (renders lid)
```

## Coupling points — change both files when modifying these

| Parameter / feature | Where defined | Affects |
|---|---|---|
| `boss_pos` (screw boss positions) | `params.scad` | Body: tap holes in corner columns; Lid: through-holes, countersinks, lip cutouts |
| `boss_d` (boss diameter) | `params.scad` | Body: column diameter; Lid: lip cutout diameter (`boss_d + 0.4`) |
| `outer_x/y` (box footprint) | `params.scad` (computed) | Body: outer cube; Lid: plate size |
| `inner_x/y` (cavity footprint) | `params.scad` (computed) | Body: cavity cutout; Lid: lip size (`inner_x - lid_lip_gap*2`) |
| `body_z` (body height) | `params.scad` (computed) | Body: column and tap hole depth; Lid: nothing directly |
| `lid_lip_h` (lip height) | `params.scad` | Lid: lip protrusion; Body: must have matching open top |
| `lid_lip_gap` (lip clearance) | `params.scad` | Lid: lip fit in body cavity |
| `screw_depth` (tap hole depth) | `params.scad` | Body: tap hole start = `body_z - screw_depth`; Lid: screw length selection |
| `wire_hole_d` (wire hole) | `params.scad` | Lid: center hole; Body: no hole (wires exit through open top) |

## Assembly

- 4× M3×16 flat-head screws through lid countersinks into body corner boss tap holes
- Lip fits into cavity with `lid_lip_gap = 0.25mm` sliding fit
- Seal perimeter with silicone or epoxy after battery insertion

## Slicing

Print separately:
- **Body** (`station_battery_mount.scad`): flat bottom down, open top up
- **Lid** (`station_battery_lid.scad`): plate face down (lip pointing up during print)
- **Stake mount** (part of mount file): stake hole down, separate print

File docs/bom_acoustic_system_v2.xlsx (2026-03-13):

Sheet: Специфікація
СПЕЦИФІКАЦІЯ КОМПЛЕКТУЮЧИХ — АКУСТИЧНА РОЗВІДУВАЛЬНА СИСТЕМА
Тестова конфігурація: 2 автономні станції + базова станція (Raspberry Pi 4)
# | Компонент | Модель / Специфікація | К-сть | Ціна за од. ($) | Сума ($) | Пошуковий запит AliExpress | Примітки
АВТОНОМНІ СТАНЦІЇ (×2)
1 | Мікроконтролер | ESP32-S3-DevKitC-1 N8R8 (8МБ Flash + 8МБ PSRAM, dual-core 240МГц) | 2 | $5.00 | $10.00 | ESP32-S3-DevKitC-1 N8R8 | Офіційний магазин Espressif на AliExpress. N8R8 = обов'язково!
2 | Мікрофон MEMS I2S | INMP441 I2S модуль (60Гц–15кГц, SNR 61дБА, 3.3В) | 8 | $2.00 | $16.00 | INMP441 I2S microphone module | По 4 шт. на станцію. Брати модулі з платою, не голий чіп
3 | LoRa радіомодуль | Ra-02 SX1278 433МГц (до 20дБм, дальність 2-5км) | 2 | $5.00 | $10.00 | Ra-02 SX1278 433MHz LoRa module | УВАГА: перевір 433МГц, не 868МГц!
4 | 2.4ГГц модуль (аудіо) | nRF24L01+ PA+LNA з антеною (до 2Мбіт/с, дальність ~800м) | 2 | $3.00 | $6.00 | nRF24L01 PA LNA SMA antenna | Версія з підсилювачем PA+LNA обов'язково
5 | Акумулятор LiFePO4 | 26650 LiFePO4 5000мА·год 3.2В (Lishen / CATL / EVE бренд) | 4 | $4.00 | $16.00 | LiFePO4 26650 5000mAh Lishen | По 2 паралельно на станцію = 10А·год, ~18 діб автономності
6 | BMS модуль | 1S BMS LiFePO4 3.2В захист (захист від перезаряду/переразряду) | 2 | $2.50 | $5.00 | 1S BMS LiFePO4 3.2V protection board | Перевір струм захисту — мін. 3А
7 | TCXO генератор | TXC 7X-25.000MBB або аналог (±0.5ppm, дрейф ~1.5мкс/год) | 2 | $3.00 | $6.00 | TCXO 25MHz 0.5ppm oscillator module | Критично для TDOA синхронізації без GPS
8 | DC-DC стабілізатор | TPS62840 або аналог 3.3В (ККД >90% при малих струмах) | 2 | $1.50 | $3.00 | TPS62840 DC-DC 3.3V step-down module | Можна брати готовий модуль на базі TPS62xxx
9 | Антена LoRa 433МГц | 433МГц штирова антена SMA (2-3dBi) | 2 | $1.50 | $3.00 | 433MHz antenna SMA 3dBi | Відповідно до роз'єму Ra-02
БАЗОВА СТАНЦІЯ / СП (×1)
10 | Одноплатний комп'ютер | Raspberry Pi 4 Model B 4ГБ (або Orange Pi 5 як альтернатива) | 1 | $50.00 | $50.00 | Raspberry Pi 4 4GB | Orange Pi 5 — альтернатива якщо RPi4 недоступний
11 | LoRa Gateway HAT | RAK2245 Pi HAT SX1301 (8 каналів одночасно, 433/868МГц) | 1 | $30.00 | $30.00 | RAK2245 Pi HAT LoRa gateway 433MHz | Альтернатива: RAK831 або SX1276 breakout + ESP32
12 | 2.4ГГц прийом аудіо | ESP32 DevKit або nRF52840 (прийом аудіофрагментів від станцій) | 1 | $4.00 | $4.00 | ESP32 DevKitC WROOM-32 | Окремий модуль для прийому аудіо каналу
13 | USB аудіоінтерфейс | Мікрофон СП — USB аудіо модуль (для запису на базовій станції) | 1 | $10.00 | $10.00 | USB audio interface microphone adapter | Або будь-який USB мікрофон з прийнятним SNR
14 | MicroSD карта | 32ГБ Class 10 / A1 (для ОС і логів) | 1 | $5.00 | $5.00 | microSD 32GB Class 10 A1 | Samsung або SanDisk — надійніші
15 | Корпус Raspberry Pi | Корпус з охолодженням для RPi4 | 1 | $5.00 | $5.00 | Raspberry Pi 4 case with fan | З вентилятором — RPi4 гріється
МОНТАЖ ТА З'ЄДНАННЯ
16 | Макетні плати | Prototype PCB двостороння (для монтажу компонентів станції) | 4 | $1.50 | $6.00 | double sided prototype PCB 7x9cm | По 2 плати на станцію
17 | Дроти та роз'єми | Dupont дроти + JST роз'єми (для з'єднань всередині станції) | 1 | $3.00 | $3.00 | Dupont wire jumper JST connector kit | Набір різних довжин і типів
18 | Корпус вуличний IP65 | Пластиковий корпус IP65 (для захисту від вологи і пилу) | 2 | $6.00 | $12.00 | IP65 waterproof junction box 150x100mm | Розмір ~150×100×70мм мінімум
19 | Кабельні вводи | PG7 / PG9 кабельні вводи (для герметичного введення проводів) | 6 | $0.50 | $3.00 | PG7 cable gland waterproof | По 3 на корпус станції
20 | Вітрозахисна насадка | Поролонова насадка для мікрофона (зменшення вітрового шуму) | 8 | $0.50 | $4.00 | microphone windscreen foam cover | Критично для вуличного використання
РАЗОМ (орієнтовно, без доставки) |  |  |  |  | $207.00 | * Ціни орієнтовні, AliExpress. Доставка ~$5-15 окремо.

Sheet: Примітки та альтернативи
КОМПОНЕНТ | ОСНОВНИЙ ВИБІР | АЛЬТЕРНАТИВА | КОМЕНТАР
Мікроконтролер | ESP32-S3-DevKitC-1 N8R8 | STM32H743 (для фінальної версії) | ESP32-S3 для прототипу, STM32 дає кращу енергетику
Мікрофон | INMP441 модуль | ICS-43434 або SPH0645LM4H-B | ICS-43434 має кращу фазову узгодженість ±0.5°
LoRa модуль | Ra-02 SX1278 433МГц | LLCC68 або RFM95W | Перевіряй частоту при замовленні!
2.4ГГц аудіо | nRF24L01+ PA+LNA | ESP32 у режимі WiFi AP | ESP32 простіший але більше споживає
Одноплатний ПК | Raspberry Pi 4 4ГБ | Orange Pi 5 / Rock Pi 4 | Orange Pi 5 дешевший і доступніший
LoRa Gateway | RAK2245 Pi HAT | RAK831 або SX1276 + ESP32 | RAK2245 може бути відсутній — мати альтернативу
Акумулятор | LiFePO4 26650 Lishen/CATL | EVE LiFePO4 26650 | Уникати no-name — завищена ємність
Корпус | IP65 пластик 150×100мм | IP67 алюміній | Алюміній краще для EMI але дорожчий

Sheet: Контекст проекту
АКУСТИЧНА РОЗВІДУВАЛЬНА СИСТЕМА — КОНТЕКСТ ПРОЕКТУ
Документ для відновлення контексту розробки. Вставити на початку нової сесії з Claude.
1. КОНЦЕПЦІЯ СИСТЕМИ
Призначення | Акустична розвідка для спостережного пункту (СП) у польових умовах. Визначення джерела, напрямку і характеру звуку в реальному часі.
Принцип роботи | Мережа автономних акустичних станцій збирає звук, обчислює TDOA (різниця часу надходження між мікрофонами), передає метадані на СП. Сервер тріангулює точну позицію джерела звуку і класифікує його (людина / тварина / транспорт).
Радіус покриття | До 3-5 км від сервера. Відстань між станціями — до 500м.
Час реакції | Одиниці секунд — прийнятно.
2. АРХІТЕКТУРА
Топологія мережі | Mesh — кожна станція є і сенсором, і ретранслятором. Немає єдиної точки відмови. При виході станції з ладу мережа перебудовується автоматично.
Два радіоканали | LoRa (433МГц, FHSS): метадані подій, керуючі команди, синхронізація — завжди активний, мінімальна радіопомітність. 2.4ГГц (nRF24L01 PA+LNA): аудіофрагменти — вмикається тільки за запитом СП на 15-20 сек.
Передача аудіо | За запитом з СП. Станція має кільцевий буфер 10-15 сек (pre+post trigger). Сервер отримує метадані від всіх станцій → обирає 1-2 з найкращим SNR → надсилає запит → станція вмикає 2.4ГГц передавач і відправляє стиснений фрагмент (Opus, 16кГц mono, ~32кбіт/с).
Мікрофон на СП | СП має власний USB мікрофон як нульова станція. Якщо подія близько (~200-500м) — аудіо є без запиту до станцій.
3D локалізація | Тетраедральний масив 4 мікрофонів на кожній станції дає 3D напрямок (азимут + елевація). Розташування: 1 мікрофон вгору, 3 горизонтально під 120°. Сервер тріангулює позицію методами Bearing Intersection + TDOA між станціями.
3. АПАРАТНА ЧАСТИНА СТАНЦІЇ
Процесор | ESP32-S3-DevKitC-1 N8R8 (8МБ Flash + 8МБ PSRAM) — для прототипу. STM32H743 — для фінальної версії (краща енергетика, 4× I2S шини).
Мікрофони | 4× INMP441 I2S модуль (прототип) або ICS-43434 (фінал, фазова узгодженість ±0.5°). Розташування тетраедральне. Вітрозахисні поролонові насадки обов'язкові.
Синхронізація часу | TCXO ±0.5ppm (дрейф ~1.5мкс/год) на кожній станції. Калібрування: акустичний маяк при розгортанні + взаємна корекція між станціями по LoRa. BEZ GPS — вразливий до РЕБ!
Живлення | LiFePO4 26650, 2 елементи паралельно = 10А·год @ 3.2В = 32Вт·год. Середнє споживання ~75мВт → автономність ~18 діб (при 0°C і вище). При -20°C: ~10-12 діб. Корпус утеплювати, підігрів при <-10°C.
Режими роботи | Очікування (95%): мікроконтролер у light sleep, аналоговий компаратор слухає (~56мВт). Обробка події (4%): пробудження, 4-канальний запис, GCC-PHAT TDOA, класифікація (~330мВт). Передача LoRa (1%): пакет 30 байт кожні кілька секунд (~400мВт × 0.5 сек).
Корпус | IP65 пластик мінімум. Кабельні вводи PG7/PG9 для герметизації. Передбачити місце для сонячної панелі (не реалізовано, але конструктивно закладено).
4. БАЗОВА СТАНЦІЯ / СП
Обладнання | Raspberry Pi 4 (4ГБ) або Orange Pi 5 як альтернатива. RAK2245 Pi HAT (SX1301, 8 каналів LoRa одночасно). Окремий ESP32 або nRF52840 для прийому аудіо по 2.4ГГц. USB мікрофон / аудіоінтерфейс для запису на СП. SSD 256ГБ для логів і аудіоархіву.
Програмна обробка | Тріангуляція позиції (Bearing Intersection + TDOA між станціями). Класифікація звуку нейромережею (людина / тварина / транспорт / невідомо). Трекінг переміщення — побудова траєкторії об'єкта. Фільтрація хибних спрацювань (дощ, вітер, птахи). Інтерфейс оператора — карта з позиціями подій.
Живлення СП | 12В від авто акумулятора або окремий LiFePO4 100Вт·год блок.
5. СИНХРОНІЗАЦІЯ БЕЗ GPS (захист від РЕБ)
Проблема | GPS/GNSS вразливий до спуфінгу і придушення в умовах РЕБ. Втрата GPS одразу ламає TDOA між станціями.
Рішення — акустичний маяк | При розгортанні: пристрій з відомими координатами генерує короткий імпульс за внутрішнім годинником. Всі станції фіксують час надходження → сервер обчислює відносні затримки → калібрує годинники. GPS потрібен тільки одноразово при встановленні (один пристрій, потім вимикається).
Рішення — взаємна корекція | Станції обміюються мітками часу по LoRa mesh і взаємно коригують дрейф (distributed clock sync). Точність ~1-5мс — достатньо для тріангуляції на дистанціях 300-500м.
Деградація без синхронізації | TCXO дрейфує ~1.5мкс/год. Без корекції через 1 годину похибка позиції ~0.5м, через 24 години ~12м. Система продовжує працювати в деградованому режимі.
Координати станцій | Вимірюються одним GPS пристроєм послідовно при розгортанні. Вводяться в сервер вручну або передаються одноразово. Після цього GPS вимикається.
6. ТЕСТОВА КОНФІГУРАЦІЯ (ПОТОЧНИЙ ЕТАП)
Склад тестової системи | 2× автономні станції (ESP32-S3 + 4×INMP441 + Ra-02 LoRa + nRF24L01) 1× базова станція — Raspberry Pi 4 + RAK2245 HAT Розміщення рівностороннім трикутником ~300м сторона.
Що перевіряємо | TDOA локалізація всередині станції (напрямок на джерело звуку) Передача метаданих по LoRa Тріангуляція між 2 станціями + СП (3 точки = мінімум для 2D) Протокол запиту і передачі аудіофрагменту Синхронізація часу між вузлами Енергетика і автономність в реальних умовах
Етапи розробки | Етап 1: Один вузол на столі — 4-канальний запис + GCC-PHAT TDOA (1-2 тижні) Етап 2: Зв'язок з базою — LoRa метадані + nRF24 аудіо протокол (1 тиждень) Етап 3: Два вузли на вулиці — тріангуляція реального джерела, точність (1-2 тижні) Етап 4: Програмна обробка на СП — карта, класифікація, інтерфейс оператора
Поточний статус | Закупка компонентів. Далі — Етап 1.
7. КЛЮЧОВІ ПРИЙНЯТІ РІШЕННЯ
Без GPS | Виключено через вразливість до РЕБ. Синхронізація — акустичний маяк + TCXO + взаємна корекція.
Двоканальна радіоархітектура | LoRa для метаданих (завжди активний), 2.4ГГц тільки для аудіо за запитом (вмикається на ~15-20 сек).
Аудіо тільки за запитом | Станція зберігає кільцевий буфер 10-15 сек. СП обирає найкращу станцію по SNR і запитує фрагмент.
LoRa FHSS | Стрибки по частотах для мінімальної радіопомітності і стійкості до перешкод.
Pre-trigger буфер | Запис починається ДО виявлення події — найцінніша частина звуку зберігається.
Температурна поправка | Кожна станція передає температуру — швидкість звуку змінюється 0.6м/с на градус, при 1-2км це метри похибки.
LiFePO4 26650 | Краща хімія для вуличних умов і морозу. Підігрів корпусу при <-10°C.
ESP32-S3 для прототипу | STM32H743 — для фінальної версії (краща енергетика у активному режимі).
8. СТРУКТУРА LORA ПАКЕТУ (~30 БАЙТ)
Station ID | 2 байти — ідентифікатор станції
Timestamp | 8 байт — мікросекунди, синхронізовано по TCXO
TDOA між мікрофонами | 4×4 байти — попарні затримки між 4 мікрофонами
SNR по каналах | 4×1 байт — рівень сигнал/шум кожного мікрофона
Попередній клас події | 1 байт — людина / тварина / транспорт / невідомо
Confidence | 1 байт — впевненість класифікації (0-100%)
Рівень заряду | 1 байт — відсоток заряду акумулятора
Температура | 1 байт — для корекції швидкості звуку
Версія документу: 1.0 | Для відновлення контексту вставити цей текст на початку нової сесії з Claude

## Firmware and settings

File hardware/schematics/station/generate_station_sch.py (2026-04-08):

#!/usr/bin/env python3
"""Generate KiCad 8 schematic for Autonomous Acoustic Station."""

import json
import uuid
import os

# Deterministic UUID generator
_uuid_counter = 0
def make_uuid():
    global _uuid_counter
    _uuid_counter += 1
    return str(uuid.uuid5(uuid.NAMESPACE_DNS, f"acoustic-station-sch-{_uuid_counter}"))

ROOT_UUID = "f47ac10b-58cc-4372-a567-0e02b2c3d479"

# ── Symbol definitions (lib coords: y-up) ──────────────────────

def rect(x1, y1, x2, y2):
    return f"""      (rectangle
        (start {x1} {y1})
        (end {x2} {y2})
        (stroke (width 0.254) (type default))
        (fill (type background))
      )"""

def pin(ptype, name, number, x, y, angle, length=2.54):
    return f"""      (pin {ptype} line
        (at {x} {y} {angle})
        (length {length})
        (name "{name}" (effects (font (size 1.27 1.27))))
        (number "{number}" (effects (font (size 1.27 1.27))))
      )"""

def lib_symbol(name, graphics_body, pins_body, desc=""):
    return f"""    (symbol "{name}"
      (pin_names (offset 1.016))
      (exclude_from_sim no)
      (in_bom yes)
      (on_board yes)
      (symbol "{name}_0_1"
{graphics_body}
      )
      (symbol "{name}_1_1"
{pins_body}
      )
    )"""

def make_lib_symbols():
    symbols = []

    # ── ESP32-S3-DevKitC-1 ──
    # 13 pins left, 8 pins right
    esp_rect = rect(-12.7, -17.78, 12.7, 17.78)
    esp_pins = []
    left_pins = [
        ("power_in", "3V3",    "1",  15.24),
        ("power_in", "GND",    "2",  12.7),
        ("bidirectional", "GPIO3",  "3",  10.16),
        ("bidirectional", "GPIO4",  "4",  7.62),
        ("bidirectional", "GPIO5",  "5",  5.08),
        ("bidirectional", "GPIO6",  "6",  2.54),
        ("bidirectional", "GPIO7",  "7",  0),
        ("bidirectional", "GPIO8",  "8",  -2.54),
        ("bidirectional", "GPIO9",  "9",  -5.08),
        ("bidirectional", "GPIO10", "10", -7.62),
        ("bidirectional", "GPIO11", "11", -10.16),
        ("bidirectional", "GPIO12", "12", -12.7),
        ("bidirectional", "GPIO13", "13", -15.24),
    ]
    for ptype, pname, pnum, py in left_pins:
        esp_pins.append(pin(ptype, pname, pnum, -15.24, py, 0))
    right_pins = [
        ("bidirectional", "GPIO14", "14", 10.16),
        ("bidirectional", "GPIO15", "15", 7.62),
        ("bidirectional", "GPIO16", "16", 5.08),
        ("bidirectional", "GPIO17", "17", 2.54),
        ("bidirectional", "GPIO18", "18", 0),
        ("bidirectional", "GPIO19", "19", -2.54),
        ("bidirectional", "GPIO20", "20", -5.08),
        ("bidirectional", "GPIO21", "21", -7.62),
    ]
    for ptype, pname, pnum, py in right_pins:
        esp_pins.append(pin(ptype, pname, pnum, 15.24, py, 180))
    symbols.append(lib_symbol("ESP32_S3_DevKitC1", esp_rect, "\n".join(esp_pins)))

    # ── INMP441 Breakout ──
    mic_rect = rect(-7.62, -5.08, 7.62, 5.08)
    mic_pins = "\n".join([
        pin("power_in", "VDD", "1", -10.16, 2.54, 0),
        pin("power_in", "GND", "2", -10.16, 0, 0),
        pin("input",    "L/R", "3", -10.16, -2.54, 0),
        pin("input",    "SCK", "4", 10.16, 2.54, 180),
        pin("input",    "WS",  "5", 10.16, 0, 180),
        pin("output",   "SD",  "6", 10.16, -2.54, 180),
    ])
    symbols.append(lib_symbol("INMP441_Breakout", mic_rect, mic_pins))

    # ── Ra-02 SX1278 LoRa ──
    lora_rect = rect(-10.16, -10.16, 10.16, 10.16)
    lora_pins = "\n".join([
        pin("power_in", "VCC",  "1", -12.7, 7.62, 0),
        pin("power_in", "GND",  "2", -12.7, 5.08, 0),
        pin("output",   "DIO0", "3", -12.7, -5.08, 0),
        pin("input",    "RST",  "4", -12.7, -7.62, 0),
        pin("input",    "MOSI", "5", 12.7, 7.62, 180),
        pin("output",   "MISO", "6", 12.7, 5.08, 180),
        pin("input",    "SCK",  "7", 12.7, 2.54, 180),
        pin("input",    "NSS",  "8", 12.7, -2.54, 180),
    ])
    symbols.append(lib_symbol("Ra02_SX1278", lora_rect, lora_pins))

    # ── nRF24L01 PA+LNA ──
    nrf_rect = rect(-10.16, -10.16, 10.16, 10.16)
    nrf_pins = "\n".join([
        pin("power_in", "VCC",  "1", -12.7, 7.62, 0),
        pin("power_in", "GND",  "2", -12.7, 5.08, 0),
        pin("input",    "CE",   "3", -12.7, -5.08, 0),
        pin("output",   "IRQ",  "4", -12.7, -7.62, 0),
        pin("input",    "MOSI", "5", 12.7, 7.62, 180),
        pin("output",   "MISO", "6", 12.7, 5.08, 180),
        pin("input",    "SCK",  "7", 12.7, 2.54, 180),
        pin("input",    "CSN",  "8", 12.7, -2.54, 180),
    ])
    symbols.append(lib_symbol("nRF24L01_PA_LNA", nrf_rect, nrf_pins))

    # ── DS3231 RTC ──
    rtc_rect = rect(-7.62, -5.08, 7.62, 5.08)
    rtc_pins = "\n".join([
        pin("power_in",    "VCC", "1", -10.16, 2.54, 0),
        pin("power_in",    "GND", "2", -10.16, -2.54, 0),
        pin("bidirectional","SDA", "3", 10.16, 2.54, 180),
        pin("input",       "SCL", "4", 10.16, -2.54, 180),
    ])
    symbols.append(lib_symbol("DS3231_RTC", rtc_rect, rtc_pins))

    # ── Mini360 DC-DC ──
    reg_rect = rect(-7.62, -5.08, 7.62, 5.08)
    reg_pins = "\n".join([
        pin("power_in",  "IN",  "1", -10.16, 2.54, 0),
        pin("power_in",  "GND", "2", -10.16, -2.54, 0),
        pin("power_out", "OUT", "3", 10.16, 0, 180),
    ])
    symbols.append(lib_symbol("Mini360_DCDC", reg_rect, reg_pins))

    # ── Li-Ion Battery 2S2P ──
    bat_rect = rect(-7.62, -5.08, 7.62, 5.08)
    bat_pins = "\n".join([
        pin("power_out", "POS", "1", 10.16, 2.54, 180),
        pin("power_out", "NEG", "2", -10.16, -2.54, 0),
    ])
    symbols.append(lib_symbol("Li_Ion_2S2P", bat_rect, bat_pins))

    # ── Power symbols: +3V3, GND, VBAT ──
    # Note: no "power:" prefix in inline lib_symbols — KiCad can't parse it in sub-symbol names
    pwr_3v3 = """    (symbol "+3V3"
      (power)
      (pin_names (offset 0))
      (exclude_from_sim no)
      (in_bom yes)
      (on_board yes)
      (symbol "+3V3_0_1"
        (polyline
          (pts (xy -0.762 1.27) (xy 0 2.54))
          (stroke (width 0) (type default))
          (fill (type none))
        )
        (polyline
          (pts (xy 0 0) (xy 0 2.54))
          (stroke (width 0) (type default))
          (fill (type none))
        )
        (polyline
          (pts (xy 0 2.54) (xy 0.762 1.27))
          (stroke (width 0) (type default))
          (fill (type none))
        )
      )
      (symbol "+3V3_1_1"
        (pin power_in line
          (at 0 0 90)
          (length 0)
          (name "+3V3" (effects (font (size 1.27 1.27))))
          (number "1" (effects (font (size 1.27 1.27))))
        )
      )
    )"""

    pwr_gnd = """    (symbol "GND"
      (power)
      (pin_names (offset 0))
      (exclude_from_sim no)
      (in_bom yes)
      (on_board yes)
      (symbol "GND_0_1"
        (polyline
          (pts (xy 0 0) (xy 0 -1.27) (xy -1.27 -1.27) (xy 0 -2.54) (xy 1.27 -1.27) (xy 0 -1.27))
          (stroke (width 0) (type default))
          (fill (type none))
        )
      )
      (symbol "GND_1_1"
        (pin power_in line
          (at 0 0 270)
          (length 0)
          (name "GND" (effects (font (size 1.27 1.27))))
          (number "1" (effects (font (size 1.27 1.27))))
        )
      )
    )"""

    pwr_vbat = """    (symbol "VBAT"
      (power)
      (pin_names (offset 0))
      (exclude_from_sim no)
      (in_bom yes)
      (on_board yes)
      (symbol "VBAT_0_1"
        (polyline
          (pts (xy -0.762 1.27) (xy 0 2.54))
          (stroke (width 0) (type default))
          (fill (type none))
        )
        (polyline
          (pts (xy 0 0) (xy 0 2.54))
          (stroke (width 0) (type default))
          (fill (type none))
        )
        (polyline
          (pts (xy 0 2.54) (xy 0.762 1.27))
          (stroke (width 0) (type default))
          (fill (type none))
        )
      )
      (symbol "VBAT_1_1"
        (pin power_in line
          (at 0 0 90)
          (length 0)
          (name "VBAT" (effects (font (size 1.27 1.27))))
          (number "1" (effects (font (size 1.27 1.27))))
        )
      )
    )"""

    symbols.extend([pwr_3v3, pwr_gnd, pwr_vbat])
    return "\n\n".join(symbols)


# ── Symbol placement and wiring ─────────────────────────────

def symbol_instance(lib_id, ref, value, desc, sx, sy, rot=0):
    uid = make_uuid()
    return f"""  (symbol
    (lib_id "{lib_id}")
    (at {sx} {sy} {rot})
    (unit 1)
    (exclude_from_sim no)
    (in_bom yes)
    (on_board yes)
    (dnp no)
    (uuid "{uid}")
    (property "Reference" "{ref}"
      (at {sx} {sy - 22} 0)
      (effects (font (size 1.27 1.27)))
    )
    (property "Value" "{value}"
      (at {sx} {sy - 20} 0)
      (effects (font (size 1.27 1.27)))
    )
    (property "Footprint" ""
      (at {sx} {sy} 0)
      (effects (font (size 1.27 1.27)) hide)
    )
    (property "Datasheet" ""
      (at {sx} {sy} 0)
      (effects (font (size 1.27 1.27)) hide)
    )
    (property "Description" "{desc}"
      (at {sx} {sy} 0)
      (effects (font (size 1.27 1.27)) hide)
    )
    (instances
      (project "station"
        (path "/{ROOT_UUID}"
          (reference "{ref}")
          (unit 1)
        )
      )
    )
  )"""


def power_instance(lib_id, ref, sx, sy):
    """Place a power symbol (+3V3, GND, VBAT)."""
    uid = make_uuid()
    net = lib_id
    return f"""  (symbol
    (lib_id "{lib_id}")
    (at {sx} {sy} 0)
    (unit 1)
    (exclude_from_sim no)
    (in_bom yes)
    (on_board yes)
    (dnp no)
    (uuid "{uid}")
    (property "Reference" "{ref}"
      (at {sx} {sy - 3} 0)
      (effects (font (size 1.27 1.27)) hide)
    )
    (property "Value" "{net}"
      (at {sx} {sy - 5} 0)
      (effects (font (size 1.27 1.27)))
    )
    (property "Footprint" ""
      (at {sx} {sy} 0)
      (effects (font (size 1.27 1.27)) hide)
    )
    (property "Datasheet" ""
      (at {sx} {sy} 0)
      (effects (font (size 1.27 1.27)) hide)
    )
    (instances
      (project "station"
        (path "/{ROOT_UUID}"
          (reference "{ref}")
          (unit 1)
        )
      )
    )
  )"""


def wire(x1, y1, x2, y2):
    uid = make_uuid()
    return f"""  (wire
    (pts (xy {x1} {y1}) (xy {x2} {y2}))
    (stroke (width 0) (type default))
    (uuid "{uid}")
  )"""


def label(name, x, y, rot=0):
    uid = make_uuid()
    return f"""  (label "{name}"
    (at {x} {y} {rot})
    (effects (font (size 1.27 1.27)))
    (uuid "{uid}")
  )"""


def text_note(text, x, y):
    uid = make_uuid()
    return f"""  (text "{text}"
    (exclude_from_sim no)
    (at {x} {y} 0)
    (effects (font (size 2.54 2.54)) (justify left))
    (uuid "{uid}")
  )"""


# ── Main generation ─────────────────────────────────────────

def generate():
    instances = []
    wires = []
    labels_list = []
    power_syms = []
    notes = []

    # Power symbol reference counters
    pwr_ref_counter = {"3V3": 0, "GND": 0, "VBAT": 0}

    def add_power(ptype, x, y):
        """Add a power symbol and wire stub. ptype: '+3V3', 'GND', 'VBAT'."""
        lib = ptype
        key = ptype.replace("+", "")
        pwr_ref_counter[key] += 1
        ref = f"#{key}{pwr_ref_counter[key]:02d}"
        if ptype == "GND":
            # GND symbol: pin at top (y=0 in symbol, pointing down)
            # Wire goes down from pin to power symbol
            power_syms.append(power_instance(lib, ref, x, y + 2.54))
            wires.append(wire(x, y, x, y + 2.54))
        else:
            # +3V3/VBAT: pin at bottom (pointing up)
            power_syms.append(power_instance(lib, ref, x, y - 2.54))
            wires.append(wire(x, y, x, y - 2.54))

    def connect_pin(pin_sheet_x, pin_sheet_y, net_name, side):
        """Add wire stub + label from a pin endpoint.
        side: 'left' (wire goes left) or 'right' (wire goes right)."""
        stub = 7.62
        if side == "left":
            end_x = pin_sheet_x - stub
            lrot = 180
        else:
            end_x = pin_sheet_x + stub
            lrot = 0
        wires.append(wire(pin_sheet_x, pin_sheet_y, end_x, pin_sheet_y))
        labels_list.append(label(net_name, end_x, pin_sheet_y, lrot))

    def connect_pin_power(pin_sheet_x, pin_sheet_y, ptype, side):
        """Connect pin to a power symbol via wire stub."""
        stub = 5.08
        if side == "left":
            end_x = pin_sheet_x - stub
        else:
            end_x = pin_sheet_x + stub
        wires.append(wire(pin_sheet_x, pin_sheet_y, end_x, pin_sheet_y))
        add_power(ptype, end_x, pin_sheet_y)

    # ── Placement coordinates ──
    # U1: ESP32-S3 (center)
    u1_x, u1_y = 210, 155

    # MIC1-4: INMP441
    mic1_x, mic1_y = 70, 80
    mic2_x, mic2_y = 70, 110
    mic3_x, mic3_y = 70, 190
    mic4_x, mic4_y = 70, 220

    # U2: LoRa (right top)
    u2_x, u2_y = 350, 85

    # U3: nRF24 (right middle)
    u3_x, u3_y = 350, 155

    # U4: DS3231 (right bottom)
    u4_x, u4_y = 350, 235

    # REG1: Mini360 (top center)
    reg_x, reg_y = 210, 38

    # BAT1: Battery (top left)
    bat_x, bat_y = 120, 38

    # ── Section notes ──
    notes.append(text_note("I2S Bus 0", 30, 60))
    notes.append(text_note("I2S Bus 1", 30, 172))
    notes.append(text_note("MCU", 195, 125))
    notes.append(text_note("Power", 145, 22))
    notes.append(text_note("LoRa 433 MHz", 325, 63))
    notes.append(text_note("nRF24 2.4 GHz", 325, 133))
    notes.append(text_note("RTC", 335, 218))

    # ── Component instances ──

    instances.append(symbol_instance(
        "ESP32_S3_DevKitC1", "U1", "ESP32-S3-DevKitC-1 N16R8",
        "MCU: dual-core 240MHz, 8MB Flash, 8MB PSRAM", u1_x, u1_y))

    for i, (mx, my) in enumerate([(mic1_x, mic1_y), (mic2_x, mic2_y),
                                    (mic3_x, mic3_y), (mic4_x, mic4_y)], 1):
        lr = "GND" if i in (1, 3) else "VCC"
        ch = "left" if i in (1, 3) else "right"
        instances.append(symbol_instance(
            "INMP441_Breakout", f"MIC{i}", "INMP441",
            f"I2S MEMS mic, L/R={lr} ({ch} channel)", mx, my))

    instances.append(symbol_instance(
        "Ra02_SX1278", "U2", "Ra-02 SX1278",
        "LoRa 433 MHz, FHSS, SPI", u2_x, u2_y))

    instances.append(symbol_instance(
        "nRF24L01_PA_LNA", "U3", "nRF24L01 PA+LNA",
        "2.4 GHz radio, SPI shared with LoRa", u3_x, u3_y))

    instances.append(symbol_instance(
        "DS3231_RTC", "U4", "DS3231",
        "RTC with TCXO, I2C, temperature sensor", u4_x, u4_y))

    instances.append(symbol_instance(
        "Mini360_DCDC", "REG1", "Mini360",
        "DC-DC buck 7.4V to 3.3V", reg_x, reg_y))

    instances.append(symbol_instance(
        "Li_Ion_2S2P", "BAT1", "Li-Ion 21700 2S2P",
        "4x Li-Ion 21700: 2S2P, 7.4V nom, ~67Wh", bat_x, bat_y))

    # ── Pin connections ──
    # Helper: compute sheet position of a pin
    # sheet_x = inst_x + pin_x, sheet_y = inst_y - pin_y  (y-up in lib → y-down on sheet)

    # U1 ESP32-S3 left side pins
    esp_left = [
        (15.24,  "+3V3"),      # VDD
        (12.7,   "GND"),       # GND
        (10.16,  "I2C_SDA"),   # GPIO3
        (7.62,   "I2C_SCL"),   # GPIO4
        (5.08,   "NRF_IRQ"),   # GPIO5
        (2.54,   "NRF_CE"),    # GPIO6
        (0,      "NRF_CSN"),   # GPIO7
        (-2.54,  "LORA_RST"),  # GPIO8
        (-5.08,  "LORA_DIO0"), # GPIO9
        (-7.62,  "LORA_NSS"),  # GPIO10
        (-10.16, "SPI_MOSI"),  # GPIO11
        (-12.7,  "SPI_SCK"),   # GPIO12
        (-15.24, "SPI_MISO"),  # GPIO13
    ]
    for pin_y, net in esp_left:
        sx = u1_x + (-15.24)
        sy = u1_y - pin_y
        if net in ("+3V3",):
            connect_pin_power(sx, sy, "+3V3", "left")
        elif net == "GND":
            connect_pin_power(sx, sy, "GND", "left")
        else:
            connect_pin(sx, sy, net, "left")

    # U1 ESP32-S3 right side pins
    esp_right = [
        (10.16,  "I2S0_SCK"),      # GPIO14
        (7.62,   "I2S0_WS"),       # GPIO15
        (5.08,   "I2S0_DATA_M1"),  # GPIO16
        (2.54,   "I2S0_DATA_M2"),  # GPIO17
        (0,      "I2S1_SCK"),      # GPIO18
        (-2.54,  "I2S1_WS"),       # GPIO19
        (-5.08,  "I2S1_DATA_M3"), # GPIO20
        (-7.62,  "I2S1_DATA_M4"), # GPIO21
    ]
    for pin_y, net in esp_right:
        sx = u1_x + 15.24
        sy = u1_y - pin_y
        connect_pin(sx, sy, net, "right")

    # ── INMP441 mic connections ──
    mic_configs = [
        # (inst_x, inst_y, lr_net, bus_prefix, data_net)
        (mic1_x, mic1_y, "GND",  "I2S0", "I2S0_DATA_M1"),
        (mic2_x, mic2_y, "+3V3", "I2S0", "I2S0_DATA_M2"),
        (mic3_x, mic3_y, "GND",  "I2S1", "I2S1_DATA_M3"),
        (mic4_x, mic4_y, "+3V3", "I2S1", "I2S1_DATA_M4"),
    ]
    for mx, my, lr_net, bus, data_net in mic_configs:
        # Left pins: VDD(y=2.54), GND(y=0), L/R(y=-2.54)
        vdd_sx, vdd_sy = mx - 10.16, my - 2.54
        gnd_sx, gnd_sy = mx - 10.16, my
        lr_sx,  lr_sy  = mx - 10.16, my + 2.54

        connect_pin_power(vdd_sx, vdd_sy, "+3V3", "left")
        connect_pin_power(gnd_sx, gnd_sy, "GND", "left")
        if lr_net == "GND":
            connect_pin_power(lr_sx, lr_sy, "GND", "left")
        else:
            connect_pin_power(lr_sx, lr_sy, "+3V3", "left")

        # Right pins: SCK(y=2.54), WS(y=0), SD(y=-2.54)
        sck_sx, sck_sy = mx + 10.16, my - 2.54
        ws_sx,  ws_sy  = mx + 10.16, my
        sd_sx,  sd_sy  = mx + 10.16, my + 2.54

        connect_pin(sck_sx, sck_sy, f"{bus}_SCK", "right")
        connect_pin(ws_sx, ws_sy, f"{bus}_WS", "right")
        connect_pin(sd_sx, sd_sy, data_net, "right")

    # ── Ra-02 LoRa (U2) ──
    # Left: VCC(y=7.62), GND(y=5.08), DIO0(y=-5.08), RST(y=-7.62)
    for pin_y, net, is_pwr in [
        (7.62, "+3V3", True), (5.08, "GND", True),
        (-5.08, "LORA_DIO0", False), (-7.62, "LORA_RST", False)
    ]:
        sx = u2_x - 12.7
        sy = u2_y - pin_y
        if is_pwr:
            connect_pin_power(sx, sy, net, "left")
        else:
            connect_pin(sx, sy, net, "left")

    # Right: MOSI(y=7.62), MISO(y=5.08), SCK(y=2.54), NSS(y=-2.54)
    for pin_y, net in [
        (7.62, "SPI_MOSI"), (5.08, "SPI_MISO"),
        (2.54, "SPI_SCK"), (-2.54, "LORA_NSS")
    ]:
        sx = u2_x + 12.7
        sy = u2_y - pin_y
        connect_pin(sx, sy, net, "right")

    # ── nRF24L01 (U3) ──
    for pin_y, net, is_pwr in [
        (7.62, "+3V3", True), (5.08, "GND", True),
        (-5.08, "NRF_CE", False), (-7.62, "NRF_IRQ", False)
    ]:
        sx = u3_x - 12.7
        sy = u3_y - pin_y
        if is_pwr:
            connect_pin_power(sx, sy, net, "left")
        else:
            connect_pin(sx, sy, net, "left")

    for pin_y, net in [
        (7.62, "SPI_MOSI"), (5.08, "SPI_MISO"),
        (2.54, "SPI_SCK"), (-2.54, "NRF_CSN")
    ]:
        sx = u3_x + 12.7
        sy = u3_y - pin_y
        connect_pin(sx, sy, net, "right")

    # ── DS3231 (U4) ──
    for pin_y, net, is_pwr in [
        (2.54, "+3V3", True), (-2.54, "GND", True)
    ]:
        sx = u4_x - 10.16
        sy = u4_y - pin_y
        connect_pin_power(sx, sy, net, "left")

    for pin_y, net in [(2.54, "I2C_SDA"), (-2.54, "I2C_SCL")]:
        sx = u4_x + 10.16
        sy = u4_y - pin_y
        connect_pin(sx, sy, net, "right")

    # ── Mini360 (REG1) ──
    # Left: IN(y=2.54) → VBAT, GND(y=-2.54)
    connect_pin_power(reg_x - 10.16, reg_y - 2.54, "VBAT", "left")
    connect_pin_power(reg_x - 10.16, reg_y + 2.54, "GND", "left")
    # Right: OUT(y=0) → +3V3
    connect_pin_power(reg_x + 10.16, reg_y, "+3V3", "right")

    # ── Battery (BAT1) ──
    # POS at right (pin_y=2.54): VBAT
    connect_pin_power(bat_x + 10.16, bat_y - 2.54, "VBAT", "right")
    # NEG at left (pin_y=-2.54): GND
    connect_pin_power(bat_x - 10.16, bat_y + 2.54, "GND", "left")

    # ── Assemble schematic ──
    sch = f"""(kicad_sch
  (version 20231120)
  (generator "eeschema")
  (generator_version "8.0")
  (uuid "{ROOT_UUID}")

  (paper "A3")

  (title_block
    (title "Autonomous Acoustic Station — ESP32-S3")
    (date "2026-04-07")
    (rev "1.0")
    (comment 1 "4x INMP441 + LoRa Ra-02 + nRF24L01 PA+LNA + DS3231")
    (comment 2 "I2S: 32kHz/16-bit, Ring buffer 3.84MB in PSRAM")
    (comment 3 "Li-Ion 21700 2S2P, Mini360 buck 7.4V->3.3V")
  )

  (lib_symbols
{make_lib_symbols()}
  )

{"".join(notes)}
{"".join(instances)}
{"".join(power_syms)}
{"".join(wires)}
{"".join(labels_list)}

  (sheet_instances
    (path "/"
      (page "1")
    )
  )
)
"""
    return sch


def generate_pro():
    return json.dumps({
        "meta": {
            "filename": "station.kicad_pro",
            "version": 1
        },
        "project": {
            "created": "2026-04-07 00:00:00",
            "meta": {
                "version": 2
            },
            "net_settings": {
                "classes": [{
                    "bus_width": 12,
                    "clearance": 0.2,
                    "diff_pair_gap": 0.25,
                    "diff_pair_via_gap": 0.25,
                    "diff_pair_width": 0.2,
                    "line_style": 0,
                    "microvia_diameter": 0.3,
                    "microvia_drill": 0.1,
                    "name": "Default",
                    "pcb_color": "rgba(0, 0, 0, 0.000)",
                    "schematic_color": "rgba(0, 0, 0, 0.000)",
                    "track_width": 0.2,
                    "via_diameter": 0.6,
                    "via_drill": 0.3,
                    "wire_width": 6
                }]
            },
            "schematic": {
                "legacy_lib_dir": "",
                "legacy_lib_list": []
            },
            "sheets": []
        }
    }, indent=2)
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

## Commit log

2026-03-13 Initial commit: acoustic reconnaissance system
    Distributed acoustic sensor network for field observation posts.
    Includes hardware OpenSCAD models, firmware stubs (ESP32-S3 station +
    TTGO gateway), server scaffold, full technical docs, and CLAUDE.md.
    [bom_acoustic_system_v2.xlsx, station_battery_mount.scad, station_electronics_compartment.scad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]
2026-03-13 Move M3 screw bosses from external corners to internal cavity corners
    Bosses now sit inside the box (tangent to outer walls, protruding into
    the corner space between the 4 cells and the side walls) using a nested
    difference() to prevent the inner cavity from eating the columns.
    Reduces boss_d to 7mm to fit within wall thickness with 1.36mm clearance
    from cell holes and 2.15mm M3 tap wall. Removes external rib module.
    [station_battery_mount.scad]
2026-03-13 Split battery compartment into params + mount + lid files
    Shared parameters extracted to station_battery_params.scad (single
    source of truth). station_battery_lid.scad is a new standalone file
    for the lid. Both include the params file. BATTERY_PARTS.md documents
    the coupling points between the three files.
    [station_battery_lid.scad, station_battery_mount.scad, station_battery_params.scad]
2026-03-16 Rework electronics compartment: dual SMA panel mounts, PCB standoffs, cleanup
    - Replace single nRF24 SMA hole with 2x panel-mount SMA (ø6.5mm) on X+ wall:
    nRF24L01 (Y-) and LoRa Ra-02 (Y+) via internal pigtail cables for IP65 sealing
    - Remove LoRa IPEX slot from top flange
    - Move PCB standoffs to match 70×90mm protoboard mounting holes:
    offset 2×2.54mm from edge → 79.84×59.84mm pattern
    - Remove USB-C programming hole — firmware via OTA (WiFi/BT)
    - Remove 4x M3 through-holes from bottom corners — battery socket handles attachment
    [station_electronics_compartment.scad]
2026-03-23 Set I2S recording to 32 kHz / 16-bit for prototype; plan 44.1 kHz / 24-bit for serial
    - Prototype (ESP32-S3 + INMP441): 32 000 Hz / 16-bit
    Ring buffer 3.84 MB fits within 8 MB PSRAM; bandwidth 16 kHz covers UAV signatures
    - Serial version (STM32H743 + ICS-43434): target 44 100 Hz / 24-bit for full 20 kHz
    spectrum and 2× better GCC-PHAT TDOA resolution; requires SDRAM or ≤10 s buffer
    - Fix CLAUDE.md ring buffer size comment (was wrong 38 MB, now correct 3.84 MB)
    https://claude.ai/code/session_01NGfFWLAaKRYP7khumFdE5w
2026-03-23 Add hardware/schematics with text netlists for station and gateway
    Station netlist covers ESP32-S3 connections: 4x INMP441 I2S (32kHz/16-bit),
    Ra-02 LoRa SPI, nRF24L01 shared SPI, DS3231 I2C, power rails.
    Gateway netlist covers TTGO LoRa32 nRF24 connections.
    Intended as KiCad-compatible reference for future PCB design stage.
    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
2026-03-23 Add hardware/schematics/README.md in Ukrainian
    Describes directory contents, KiCad 8 + skidl toolchain recommendation,
    prototype recording params (32kHz/16-bit), and serial version targets
    (STM32H743 + ICS-43434, 44.1kHz/24-bit).
    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
2026-03-25 Switch 3D modeling toolchain from OpenSCAD to build123d
    Document build123d + ocp-vscode as the new toolchain for parametric
    hardware enclosure design. Legacy .scad files marked as such.
    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
2026-03-25 Add enclosure design discussion notes
    Captures new enclosure concept: top housing with all electronics,
    flat bottom lid recessed with countersunk screws and perimeter ledge.
    Open questions listed for next discussion session.
    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
2026-03-26 Switch battery spec from 26650 to 21700 LiFePO4
    Update cell dimensions (⌀21×70mm), capacity (~8Ah / ~25Wh),
    and autonomy estimates. Update enclosure discussion with resolved
    parameters table (PCB 70×90mm, 2×21700 batteries).
    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
2026-03-26 Switch battery to Li-ion 21700 2S2P (4 cells)
    7.4V nominal, ~67Wh, ~30 days autonomy. Buck converter 7.4→3.3V
    now mandatory. 2S BMS required. Note Li-ion cold-temp penalty vs
    previous LiFePO4 rationale.
    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
2026-03-26 Continue working
    [_section_view.scad, station_mic_lid.scad]
2026-03-27 Fix architecture docs: add station 0 ESP32-S3, correct mic geometry and stage status
    - Station 0: ESP32-S3 N16R8 with INMP441s via USB CDC (not USB mic on Rock Pi)
    - TTGO gateway: remove erroneous INMP441 section — radio bridge only
    - CLAUDE.md: tetrahedral mic geometry — add 35° tilt from vertical
    - Stage 1 status: In progress → Pending (components not yet purchased)
    - Docs: harmonize battery autonomy (67 Wh, ~30 days) across both locations
2026-04-08 Add KiCad 8 schematic project for autonomous station
    Generated from station_netlist.txt: ESP32-S3 + 4x INMP441 + LoRa Ra-02 +
    nRF24L01 + DS3231 + Mini360 + Li-Ion 2S2P. All 20 nets wired via labels.
    Includes Python generator script for reproducible regeneration.
    [station.kicad_sch]
2026-04-08 Remove legacy OpenSCAD files — migrated to build123d
    All 6 .scad files removed: station_battery_params, station_battery_mount,
    station_battery_lid, station_electronics_compartment, station_mic_lid,
    _section_view. New 3D models will be created in build123d (Python).
    [_section_view.scad, station_battery_lid.scad, station_battery_mount.scad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]
2026-04-08 Move station KiCad project to own subfolder
    hardware/schematics/station/ now contains: .kicad_pro, .kicad_sch,
    station_netlist.txt, and generate_station_sch.py.
    [station.kicad_sch]
2026-04-08 Add project structure convention and station .gitignore
    CLAUDE.md: subsystem subfolder rule for schematics, models, firmware.
    .gitignore: exclude KiCad backups, .kicad_prl, lock files, .history.
2026-04-08 Add root .gitignore, remove redundant station-level one
    Covers IDE, OS, Python, ESP-IDF, KiCad, and .history globally.
